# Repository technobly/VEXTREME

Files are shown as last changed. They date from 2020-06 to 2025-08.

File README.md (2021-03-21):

VEXTREME Vectrex Multicart
===

We're carrying on and pushing forward the amazing work of [Sprite_tm](http://spritesmods.com/?art=veccart&page=1) and his Extreme Vectrex Multicart. He posted the code (GPLv3 License) and lots of screens of the PCB/initial schematic, but he never released the PCB. It's a great base for an inexpensive and open vectrex multicart, for developers and players alike!

:warning: Please read this NOTICE of Current Development :warning:
===

**This project is a work in progress, and is not ready for mass production.**  Please observe the currently [posted issues](https://github.com/technobly/vextreme/issues) and there may be more lurking that are not yet identified.  The hardware and software is evolving.  You are free to build any version, contribute and/or follow along.  Please note that support of these pre-releases will be very limited and if you embark on an epic adventure to build one or a few, you should feel comfortable with this type of embedded hardware and software development.  There will be road bumps, but the journey is half the fun of the destination.  When things appear to be stable and we've worked out most of the kinks, we'll change the version to v1.0.  Only then is it advisable to mass produce.

3D Renders
===

v0.2 Render

Video Updates
===

Be sure to subscribe to my Youtube channel for updates!  Here's my [Vectrex playlist](https://www.youtube.com/watch?v=zkJ-z77fJCw&list=PL7MgXfpGKg6CCaIQejZVb5CsTg3-5mHU0&index=1) if you want to stay laser focused on this project.

VEXTREME Discord Server
===
Join the [VEXTREME Discord server](https://discord.gg/VDssGVJ) to chat with us about the development

BOM and Parts ordering
===

All the parts are described in Bill of Materials [vextreme-v0.x.csv](bom/)

Also, you can use this [Digi-Key shared cart](https://www.digikey.com/short/zpdmtp) if you're in a hurry.  It has will have part references right on the packages for you!

Ordering PCB's
===

OSHPark is a good place to order with purple or the new "after dark" theme color scheme.  You can upload the KiCad [vextreme.kicad_pcb](hardware/vextreme.kicad_pcb) there directly.  I would download this entire Github repo ZIP file first though instead of just trying to save the PCB file from your browser.

Another way to order PCB's is by using the included [gerbers-vextreme-v0.x.zip](gerbers) and uploading those with all of the necessary specs to companies like [PCBWay](https://www.pcbway.com) or [JLCPCB](https://jlcpcb.com)

Building and Flashing STM firmware
===

### This assumes you have these prerequisits installed:

- Docker
- dfu-util v0.9
- Make
- Windows will also require these [Zadig instructions](https://github.com/profezzorn/ProffieOS/wiki/zadig)

### Build the stm32-build docker image
```
code/stm32 $ make docker-build
```

### Connect the 2-pin jumper and then connect the cart to USB

### Check if your computer sees the STM32
```
$ dfu-util -l

dfu-util 0.9

Copyright 2005-2009 Weston Schmidt, Harald Welte and OpenMoko Inc.
Copyright 2010-2019 Tormod Volden and Stefan Schmidt
This program is Free Software and has ABSOLUTELY NO WARRANTY
Please report bugs to http://sourceforge.net/p/dfu-util/tickets/

Deducing device DFU version from functional descriptor length
Found DFU: [0483:df11] ver=2200, devnum=22, cfg=1, intf=0, path="20-1.4.3", alt=3, name="@Device Feature/0xFFFF0000/01*004 e", serial="123412341234"
Found DFU: [0483:df11] ver=2200, devnum=22, cfg=1, intf=0, path="20-1.4.3", alt=2, name="@OTP Memory /0x1FFF7800/01*512 e,01*016 e", serial="123412341234"
Found DFU: [0483:df11] ver=2200, devnum=22, cfg=1, intf=0, path="20-1.4.3", alt=1, name="@Option Bytes  /0x1FFFC000/01*016 e", serial="123412341234"
Found DFU: [0483:df11] ver=2200, devnum=22, cfg=1, intf=0, path="20-1.4.3", alt=0, name="@Internal Flash  /0x08000000/04*016Kg,01*064Kg,03*128Kg", serial="123412341234"
```

### Build and flash the STM32 image via dfu-util
```
code/stm32 $ make clean all flash USE_HW=v0.3

// NOTE: Use v0.2 above if you have v0.2 HW, or you may use v0.3 if you make the proper mods to your board.  See "Modifying v0.2 to v0.3"

// You should end up with something like this

Downloading to address = 0x08000000, size = 23536
Download    [=========================] 100%        23536 bytes
Download done.
File downloaded successfully
```

### Remove the cart from USB and remove the jumper (install it on one pin so you don't lose it)

Building and Flashing the multicart's menu
===

### Build the asm6809 docker image
```
code/menu $ make docker-build
```

### Connect the cart to USB with the 2-pin jumper removed

- The first time you do this you will likely have to format the USB drive

  - Name: VEXTREME
  - Format: MS-DOS (FAT)
  - Scheme: Master Boot Record
  - 512 byte page size

- Be patient, it's slow!  Don't worry, copying binaries later will be fast!!

### Build and flash the multicart menu binary
```
// Mac OS
code/menu $ make clean all && cp menu.bin /Volumes/VEXTREME/

// optionally add this to the above command to unmount, after you figure out which drive it is
$ diskutil list
&& diskutil unmountDisk /dev/disk3

// Linux
code/menu $ make copy

// You should end up with something like this, and the binary should have been copied to the root of your multicart drive

asm6809  -B -o menu.bin menu.asm
```

Modifying v0.2 to v0.3
===

v0.3 Mod 1

- To get the new reset feature of v0.3, as of v0.24 software you will need to jumper V-OE pin 12 of the cart fingers (or U3 pin 9) to STM32 pin 29 (PB10).  This may change in the future, don't sell your soldering iron!
- The wire mod above also allows you to play Animaction on VEXTREME!
- More TBD

Adding Vectrex Game ROMs (Binaries)
===

- Create a directory on your multicart called `roms/`

- Add your first binaries there, may I suggest: [Beluga Dreams](https://8-bit-waves.itch.io/beluga-dreams) and [Vec-Man](http://eiti.fh-pforzheim.de/personen/johannsen/projektlabor/vectrex_2019/vectrex_game_vec_man.htm) ?

Docs
===

A nice collection of lessons learned will be [documented here.](docs/)

Hall of Fame
===

If you build one of these, be sure to send me a message with your build pics showing your working VEXTREME multicart!  Or better yet, check out the [hall of fame format here](hall-of-fame/) and submit a PR (please and thank you!)

Credits
===

Everyone who has contributed to this project, with a short summary of their contributions can be found here [CREDITS](CREDITS.md)

LICENSE
===

GPLv3 - essentially you must keep this open, all changes must be disclosed and shared.  Full [LICENSE here](LICENSE) and [TL;DR summary here](https://tldrlegal.com/license/gnu-general-public-license-v3-(gpl-3))

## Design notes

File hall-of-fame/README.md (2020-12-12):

Hall of Fame
===

If you build one of these, be sure to send me a message with your build pics showing your working VEXTREME multicart!  Or better yet, check out the format above and submit a PR (please and thank you!) - limit pic width to 600px please.

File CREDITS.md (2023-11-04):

VEXTREME Vectrex Multicart Credits
===

*If your contribution is not listed below, I appologize!  Please create a PR and add yourself to this list :D*

# v0.0

- [Sprite_tm aka Jeroen Domburg](https://github.com/Spritetm) - [all hardware and software](http://spritesmods.com/?art=veccart&page=1)

# v0.1

- [Bradon Kanyid](https://github.com/rattboi) - all hardware design files and software build
- [Brett Walach](https://github.com/technobly) - minor changes to hardware and software

# v0.2

- [Brett Walach](https://github.com/technobly) - lead VEXTREME developer, hardware & software updates
- [Bradon Kanyid](https://github.com/rattboi) - menu system w/directories, integrating menu.bin into STM binary.
- Tony Lindberg - VEXTREME logo design, machining consulting
- [Malban](https://github.com/malbanGit) - VEXTREME logo optimization, font-5, Vide (used to create and debug VEXTREME), Asteroids emulation
- [Tyler Brymer](https://github.com/TylerBrymer) - High score feature

# v0.3

- [Brett Walach](https://github.com/technobly) - single sided hardware redesign

# v0.4

- [Brett Walach](https://github.com/technobly) - minor hardware updates
- [Vasily Kiniv](https://github.com/v-kiniv) - vector font menu redesign, settings and screensaver features

# DEMOS / GAMES / GCE / LED / MUSIC / TOOLS / XMAS

HUGE THANK YOU TO EVERYONE THAT HAS GIVEN PERMISSION TO INCLUDE GAMES ON VEXTREME!!!

```
- GCE / MB / Jay Smith
- Brett Walach
- Chris BinaryStar
- Chris Parsons
- Clay Cowgill
- Graham Toal
- James Watt
- John Dondzilla
- John Reder
- Malban
- Michael Simmonds
- Nathan Hulett
- Ollie
- Ralf Kornmann
- Rob Mitchell
- Ville Krumlinde

Vectrex Academy
   ├── 2016
   │   ├── Absorbtex by Ana Bressel
   │   ├── Artillery Strike by Jan Langer
   │   ├── Bacteria by Matthias Bach
   │   ├── BaseLoot by Jan Hoffmann
   │   ├── Blox Breaker by Matthias Tiran
   │   ├── Brick Crusher by Tugce Ünsal, Ersin Dogan
   │   ├── Headless Runner by Timo Barth
   │   ├── Hextrex by Michael Tiran
   │   ├── Hungry Python by Maximilian Schiller
   │   ├── Hurdles by Marcel Krause
   │   ├── Laser Wars by Florian Krause
   │   ├── Last Battle by Jonas Krause
   │   ├── Robhop by Miss Lissi
   │   ├── Space Assault by Fabian Pfeifroth
   │   ├── Space Attack by Abdalla Ifen
   │   ├── Spikes by Emanuel Blindow
   │   ├── The Snake by Matthias Schneider
   │   └── Traffic Race by Dominic
   ├── 2017
   │   ├── Block Bomb by Marvin Berstecher
   │   ├── Curling by Manuel Rettig
   │   ├── Doodle Jump by Robin Schelling
   │   ├── Eating Fish by KiriCreamCheese
   │   ├── Hover Race by Simeon Schüller
   │   ├── Kingdom Of Heaven by Jan David Kurfiß
   │   ├── Knight Rider by Blondie
   │   ├── Lost Souls by Gunterson
   │   ├── Pac Men by Manuel Debic
   │   ├── Pipe Race by Ralph Gerath
   │   ├── Shark Attack by by Maximilian Kellner
   │   ├── Space Ball by Tim Stiesch
   │   ├── Space Patrol by Andreas Barth
   │   ├── Spaceship Centauri by Christoph Bechtle
   │   ├── Star Fuel by Andreas Bauer
   │   └── Star War by Marco Schewa
   ├── 2018
   │   ├── Asteroid Cowboy by A.B.
   │   ├── Asteroids by L.D.
   │   ├── Floor is lava by Volcanus
   │   ├── Keyboard Hero by W.L.
   │   ├── Portal Fight by J3W3L5
   │   ├── Pyoro-Chan by Swagger
   │   ├── Split Personality by M.S.
   │   ├── Thirsty Astronaut by Firemedic
   │   ├── Treasure Diver by Falrahch
   │   ├── Yarg! (no Overlay) by Germanke
   │   └── Yarg! by Germanke
   ├── 2019
   │   ├── Blox by Whitehat
   │   ├── Castle Defender by Jumpman
   │   ├── Castle vs Castle by Hydrochous
   │   ├── Daisy Land by Princess Daisy
   │   ├── Dino Runner by Hoid
   │   ├── Donkey Kong by Lionpride
   │   ├── Dont fall by Mr. Chomp
   │   ├── Fencing Simulator by Alberich
   │   ├── Hole-Run Speedy G.
   │   ├── Moon Shot by SchellLabs
   │   ├── Pirates by G. Freeman
   │   ├── Space Defender by KusoTech
   │   ├── Unknown by M4K5
   │   ├── Vec Man by Master Control
   │   └── Vectroid by NATE 66
   └─── 2020
       ├── Climb It by Chris++
       ├── Crash Trexicoot by LiKa
       ├── Maze Of Treasures by Sgt. Pepper
       ├── Number Cruncher by Peer Johannsen Alpha 0.1
       ├── Rotor by Peer Johannsen Beta RC 1.0
       ├── Rotor by Peer Johannsen Beta RC 1.1
       ├── Rush Defense by Compile
       └── Silver Surfer by Hassel
```

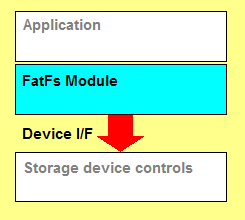
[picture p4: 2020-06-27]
code/stm32/fatfs/doc/img/layers2.png

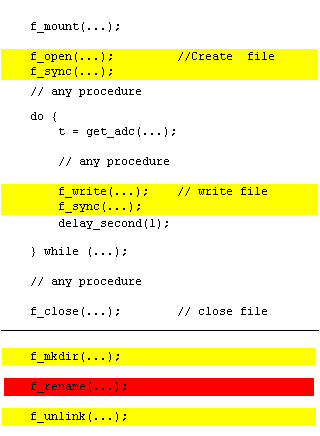
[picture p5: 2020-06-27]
code/stm32/fatfs/doc/img/f5.png

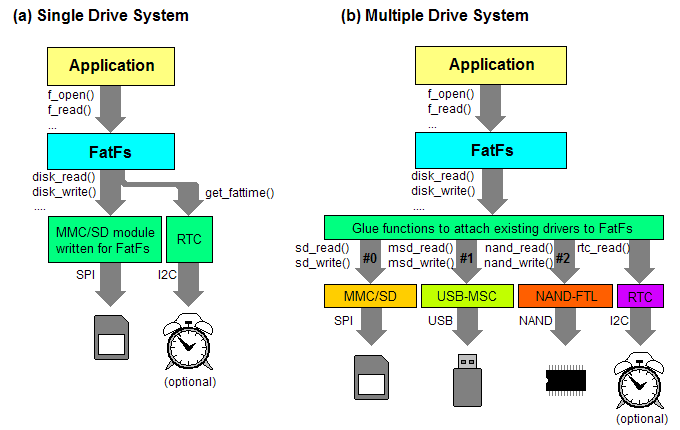
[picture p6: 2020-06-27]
code/stm32/fatfs/doc/img/funcs.png

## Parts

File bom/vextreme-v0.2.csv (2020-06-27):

Ref | Qnty | Value | Cmp name | Footprint | Description | Vendor
C1, C2, C7, C6, | 4 | 2.2u | C | Capacitor_SMD:C_0805_2012Metric_Pad1.15x1.40mm_HandSolder | Unpolarized capacitor
C4, C3, C5, C10, C11, C12, | 6 | 100nF | C | Capacitor_SMD:C_0805_2012Metric_Pad1.15x1.40mm_HandSolder | Unpolarized capacitor
C8, C9, | 2 | 18pF | C | Capacitor_SMD:C_0805_2012Metric_Pad1.15x1.40mm_HandSolder | Unpolarized capacitor
C13, | 1 | 47u | C | Capacitor_SMD:C_0805_2012Metric_Pad1.15x1.40mm_HandSolder | Unpolarized capacitor
CON1, | 1 | vectrex-edge-connector | vectrex-edge-connector | veccart:vectrex-edge-connector-thinner
D1, D2, | 2 | MBR0520 | MBR0520 | Diode_SMD:D_SOD-123 | 20V 0.5A Schottky Power Rectifier Diode, SOD-123
D3, | 1 | LED | LED | LED_SMD:LED_0805_2012Metric_Pad1.15x1.40mm_HandSolder | Light emitting diode
D13, D12, D11, D10, D9, D8, D7, D6, D5, D4, | 10 | APA102-2020 | APA102-2020 | veccart:LED-APA102-2020_6 | RGB LED with integrated controller
J1, | 1 | USB_C_Receptacle_USB2.0 | USB_C_Receptacle_USB2.0 | veccart:USB_C_Receptacle_HRO_TYPE-C-31-M-12 | USB 2.0-only Type-C Receptacle connector
J2, | 1 | Conn_01x06_Male | Conn_01x06_Male | Connector_PinHeader_2.54mm:PinHeader_1x06_P2.54mm_Vertical | Generic connector, single row, 01x06, script generated (kicad-library-utils/schlib/autogen/connector/)
JP1, | 1 | Jumper_NO_Small | Jumper_NO_Small | Connector_PinHeader_2.54mm:PinHeader_1x02_P2.54mm_Vertical | Jumper, normally open, small symbol
R1, R2, | 2 | 22 | R | Resistor_SMD:R_0805_2012Metric_Pad1.15x1.40mm_HandSolder | Resistor
R3, | 1 | 10k | R | Resistor_SMD:R_0805_2012Metric_Pad1.15x1.40mm_HandSolder | Resistor
R4, | 1 | 220 | R | Resistor_SMD:R_0805_2012Metric_Pad1.15x1.40mm_HandSolder | Resistor
R5, R6, | 2 | 5.1k | R | Resistor_SMD:R_0805_2012Metric_Pad1.15x1.40mm_HandSolder | Resistor
U1, | 1 | LM1117-3.3 | LM1117-3.3 | Package_TO_SOT_SMD:SOT-223-3_TabPin2 | 800mA Low-Dropout Linear Regulator, 3.3V fixed output, TO-220/TO-252/TO-263/SOT-223
U2, | 1 | STM32F411RCTx | STM32F411RCTx | Package_QFP:LQFP-64_10x10mm_P0.5mm | ARM Cortex-M4 MCU, 256KB flash, 128KB RAM, 100MHz, 1.7-3.6V, 50 GPIO, LQFP-64
U3, | 1 | 74HC32 | 74LS32 | Package_SO:SOIC-14_3.9x8.7mm_P1.27mm | Quad 2-input OR
U4, | 1 | SN74LVC8T245DB | SN74LVC8T245DB | Package_SO:SSOP-24_5.3x8.2mm_P0.65mm | 8-bit dual supply translating transceiver, 3-state, SSOP-24
U5, | 1 | W25Q128 | W25Q128 | Package_SO:SOIC-8_5.23x5.23mm_P1.27mm | External EEPROM with SPI interface in 8-pin package
Y1, | 1 | 8MHz | Crystal | Crystal:Crystal_SMD_5032-2Pin_5.0x3.2mm_HandSoldering | Two pin crystal

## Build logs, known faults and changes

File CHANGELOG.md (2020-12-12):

# Changelog

## v0.24

Hardware Changes

- rename 'veccart' to 'vextreme' for hardware
- add image for v0.3 wire mod
- Fixes #17, make all pads on addressable LEDS the same size
- Fixes #10 removes soldermask ink around PCB fingers
- Fixes #11 Edge of PCB fingers should be 18.0mm from center of 3.52mm mounting hole and 1.2mm from edge, and slightly enlarged (0.2mm oversized)
- Also aligns holes, fingers and board outline on 0.1mm grid

Software Changes

- Added Turkey Pop.bin to release
- Added HACKS/LEVEL SELECT/Mine Storm 1.bin to release
- Fixed GCE/Mine Storm 1.bin in release
- rename 'veccart' to 'stm32' for firmware, and rename 'multicart' to 'menu'
- Embedded menu binary in STM32 flash image
- Update Dockerfile distro to Arch w/ newer arm-gcc (10.1)
- add .map file to build output
- Dev Mode (cart.bin) and Menu (multicart.bin) should not load a high score
- made high_score_flag readable from parmRam with new RPC ID 16, and speeds memory r/w for highscore
- Implements #55 High Score (by @TylerBrymer PR #56)
- Truncate filenames displayed to 16 characters and fix long filename bug
- Reduced rainbow mode colors so that no-buzz Vectrex owners don't hear any LED modulation
- implemented Animaction support for v0.3 hardware
- made sys_opt.hw_ver usage clearer
- added RAM Write debugging application and new dumpMemory() RPC ID 13
- added a release.sh script
- added standalone Developer Mode app (note: this is for reference only, see readme.md)
- added Develop Mode docs
- added Developer Mode (DM) to Menu.  Press button 2 & 3 at any time to enter DM, or hold them down when starting the Menu.  DM will also automatic re-enter when it's active.  DM is active when a cart.bin is present, and DM can be disabled by removing cart.bin manually, or through the DM menu button 1: Exit.
- add USE_HW compile option, which must now be set.  It will not default to a specific version.  Right now specify it as USE_HW=v0.2 or USE_HW=v0.3 when running 'make clean all flash'.  It can also be exported in your environment if you wish, but don't forget about it if you update your HW ;-)
- removed :leave from DFU commands since after flashing the stm32 binary, we are not really ready to reset and run.  The boot0 jumper must be removed before then.
- minor changes to improve the Makefile for Windows (still WIP)
- changed delay() and millis() to use dwt_read_cycle_counter() instead of the sys_tick_handler() because romemu.S didn't like us randomly leaving to handle interrupts, and we need these functions while we are emulating ROM.  There is a ~35s delay limit because of this.  I added an assert so I don't forget!
- started adding some changes in fatfs to enable writes to flash memory since it was currently read-only, but ended up not needing them.  No worries though, the highscore feature will require these.  These changes thanks to @tbrymer!
- VEXTREME now also prints it's own HW and SW revision in logs at boot time.
- Moved start of rainbow LED code to after we are done with USB activities, so as not to load down the USB port more than necessary.  Hopefully this fixes a reported bug with Windows.
- USB MSC can now be entered while the Vectrex is off, Ejected and left plugged in and the Vectrex can be turned on and boot a cart.bin for Developer Mode, or the VEXTREME menu.
- USB MSC can be started and stopped from the Vectrex now, which is necessary for Developer Mode.
- An improved reset function was added after feedback from users.  Now in v0.3 hardware you will be able to press reset at any time to get back to the Menu.  If you hold reset for ~700ms, it will reset the current running ROM/game.  In the case of booting into Developer Mode (cart.bin already on the drive root), a first reset will not go to the Menu, but rather the cart.bin.. allowing you to skip the cold boot sequence. You may modify v0.2 hardware to act like v0.3 hardware for this feature.  For now that means you will need to jumper V-OE pin 12 of the cart fingers (or U3 pin 9) to STM32 pin 29 (PB10).
- For v0.2 hardware, you can still compile in the old functionality were a short reset would reset the running ROM/game, and if you hold reset for ~700ms you will get the Menu.
- Also added to the reset sequence for both v0.2/v0.3 HW is that the LEDs light up CYAN after the "long" reset delay of 700ms, and stay lit as long as you are holding reset.  When you let go, they return to rainbow.  This helps you gage just how long you need to wait to hold the button for long reset.
- Added "scsi_command: %02X\n" which logs USB MSC commands to log output, this might seem chatty, but for now let's see what we see ;-)
- Set USB power to 500mA (was set to 100mA)

## v0.23

- Fixes issue where VEXTREME takes several minutes to mount as USB drive on Windows #53

## v0.22

- ignore all file extensions that are not .bin or .vec (case insensitive) #49
- increased quick reset delay to 700ms #45 
- adds HW/SW version to VEXTREME menu and games #48 
  - see example in LED Test v1.1.bin

## v0.21

- :warning: Added NOTICE of Current Development
- Fixes Polar Rescue and implements a new Reset Heurisic #37
- Adds addressable LED control and demo #41
    - added 3 functions to control the LEDs from a Vectrex program
        - updateOne() - RPC 6
        - updateAll() - RPC 4
        - updateMulti() - RPC 7
    - added RPC function 5 to step through rainbow control of LEDs in menu
    - added "LED TEST" which uses updateMulti to show how to finely control
    all of the LEDs with a test program.  Press UP on the joystick, try it slowly as well :D
    - added addressable LED control to Veccy Bird v1.5

## v0.2

- Replaced USB-B-mini with USB-C and centered USB on cart
- Extended the PCB by 1.7 mm to get the USB-C connector as close to the case exterior as possible.
- Widened the PCB to 48.0 mm so that there’s less side to side play in the cartridge slot.
- Moved outer mounting holes into the proper locations
- Reversed D3 and R4 order to get D3 closer to edge of the PCB, but it turned out we added something else there!
- Added 10 APA102-2020 addressable RGB LED lights (max. draw 245mA) … qualify with USB-IN (PA9) for 100% brightness, else 50%
- Added 47uF cap for peak currents required for RGB LEDs.
- Added V-IRQ connection to PB9 for 128KB bank-switching
- Grounded unused floating inputs on U3 to reduce current consumption
- Adjusted Y1 to use 12pF load crystal resonator with 18pF load caps (see equation)
- Lots of clean up and tweaking all over PCB
- Added revision to PCB
- Added “VEXTREME” to PCB
- Added a ground pour under the STM32
- Made the contacts on the edge connector thinner (1.52mm) and made sure they were spaced properly (2.54mm).
- Started moving footprints to the libs/veccart.pretty library so you know where they will be!
- Add basic folder support #1
- Ignore dotfiles generated by MacOS
- Add software driven addressible LED support
- improve USB write time for a single game by 3x (32KB in 1 second)
- adds 'clean' and 'all' rules for multicart build
- create 4KB of space for menu (currently about 2KB), and reserve 60KB for menu data.
- Added a mostly optimized 100 vector logo for VEXTREME
- Added a much improved version of Malban's 5 line font (everything except lowercase, don't use lower)
- Reduced menu to 4 items at a time
- Added a special intro jingle that's been stuck in my head (enjoy!)
- temp increase time to reset to allow Fortress of Narzod to play
- Extract menu code from main code and optimize menu code
- Add basic menu labels/function-per-button support #4
    - At the bottom of the menu 1 = (BACK), 2 = PAGE LEFT, 3 = PAGE RIGHT, 4 = SELECT
- Ignore lst files #5
- adds ISSUE_TEMPLATE.md and PULL_REQUEST_TEMPLATE.md for contributions from the community
- Update to latest (pinned) libopencm3 #6
- Fixed lastselectcart on wrong game after reset
- Fixed do not inc page if next one will be blank issue
- Converts logo from sync to smart list, thanks Malban!
    - Note: Had to replace NOP MACROs with JSR of approx equivalent value
    - Converted fcb hi(label),lo(label) into fdb label
    - Reduces cycle count by 8 - 10k!

## v0.1

- Mostly unchanged from Sprite_tm's original HW/SW design
- Mostly unchanged from Rattboi's original PCB design
- fixes error opening PCB with latest KiCaD
- add gerbers for easy PCB ordering at many places
- update README.md and add LICENSE
- fixes premature automatic reset delay on GCE Vectrex
- fixes menu builder missing filename in path
- pretty up the menu by removing the .BIN file extension, and other cleanup
- let's call it the VEXTREME cart, for now. (original name was EXTREME)

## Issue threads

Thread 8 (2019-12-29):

DS243x support for High Score/etc save

gauze, 2019-12-29:
## Feature/Enhancement Request

one thing I'd be interested in seeing is emulation of the Maxim DS243x
1-wire eeprom used on various games to store high scores and
settings/options. The device is controlled through cart pin 35 (port B
bit 6 from PIA) code examples from Alex Herbert/Malban can be found in
the "include" file ds2431LowLevel.i that is in VIDE and other stuff.
The datasheet for the device describes way more functionality than
you'd need to implement the simple read/write that Vec games use.

https://datasheets.maximintegrated.com/en/ds/DS2431.pdf

thanks

technobly, 2019-12-31:
Thanks @gauze for the feature request!

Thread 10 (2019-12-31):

[PCB,v0.2] soldermask around PCB fingers

technobly, 2019-12-31:
## Bug Report

### Expected Behavior

There should be no soldermask ink/LPI surrounding the PCB fingers

### Observed Behavior

There is soldermask around the fingers, and when it's really thick it causes the contacts in the Vectrex connector to float above the PCB finger ever so slightly.  Games glitch out at different times due to addressing issues or bad data.

### References

Here's a great list of Vectrex carts that also have this issue (notice the original GCE carts pictured here DON'T have this issue but do have hard gold fingers as well...): http://vide.malban.de/collection-2/the-beauty-in-pcbs

See the issue and resolution here for v0.2: https://www.youtube.com/watch?v=sS-BKoMr4OM
The tool used in the video above is an exacto knife with the tip broken off on purpose :D

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

### If you bought a VEXTREME from Game-Tech.us, it is a v0.2 with the soldermask problem (PLEASE READ)
Is your game glitching out at random times, or only Mine Storm showing up? Your problem is almost 100% because of the soldermask that surrounds the fingers on the cart. This is why I painstakingly removed it from all v0.2 VEXTREME's that I sold for $40 USD. Jason GameTechUS knows this is a problem and sold them to you without removing the soldermask, because they might have worked in his Vectrex... I don't know his testing process... but YMMV with different connectors and varying degrees of soldermask thickness. Not trying to throw anybody under a bus here... just real talk. I don't want VEXTREME (all caps btw) to get a bad name because a pre-production version not ready for the masses was sold in high numbers. Good luck all you new owners of open source hardware, I do hope you get to enjoy VEXTREME as I intended in creating this project. I hope Jason GameTechUS stands by his sale and helps you find a solution here.

Here's a way to test if it's the fingers causing an issue: take the cart out of the shell... plug it in, play a game, and gently and slowly wiggle the cart up and down and maybe even pull it 0.5 mm in and out of the cart slot. If the game glitches out on you... soldermask is likely the issue. Try this same procedure with any production Vectrex game, and you'll see it won't glitch out... and you can also see what the limits of pulling it in and out are.

You can also try that same procedure with the game in the shell, but it won't go up and down as easily. More so in and out, and it will be worse in the case because the case holds the PCB perpendicular to the cart edge connector, so all of the fingers of the Vectrex's connector tend to float on top of the soldermask at the leading edge of the PCB.

Closed 2020-06-11.

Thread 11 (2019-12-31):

[PCB] Edge of PCB fingers should be 18.0mm from center of 3.52mm mounting hole and 1.2mm from edge, and slightly enlarged

technobly, 2019-12-31:
## Enhancement

For proper mating of the PCB to Vectrex when PCB is installed in a reproduction Vectrex cartridge enclosure, the PCB fingers should be 18.0mm from the center of the 3.52mm mounting hole and 1.2mm from the PCB edge.

This 1.2mm distance just also happens to be a requirement for hard gold PCB finger 45° edge beveling: https://jlcpcb.com/quote/pcbOrderFaq/Gold%20Fingers

See Berzerk cart measurements:
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

---

Mounting holes should also all be 0.2mm larger than the posts (currently they are 0.1mm larger and it's perfect... but too perfect of a fit)

POST - HOLE
--------------
5.0    ->    5.2
4.0    ->    4.2
3.5    ->   3.7

Closed 2020-06-11.

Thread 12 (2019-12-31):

[PCB] Remove D8 - D13 and just have addressable LEDs on the edge of the board, spacing the 4 LEDs evenly

technobly, 2019-12-31:
## Enhancement

Not much more to say other than `7mm spacing` between all 7 LEDs is some kind of jackpot I think! 🎉 💰

----

UPDATE: After more testing, 4 LEDs can but turned up to full brightness instead of using 7 LEDs.  Less cost, and same amount of light.  Yeah we have less resolution for cool light shows, but... from what I can tell everyone want to cover up the LEDs with a cart of some sort anyway.

Closed 2020-06-12.

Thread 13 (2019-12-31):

[PCB] Move the debugging/serial port connector so it does not interfere with enclosure bosses.

technobly, 2019-12-31:
## Bug Report

### Expected Behavior

Components should not be in the way of the enclosure bosses

### Observed Behavior

- 5 pin debugging header pins are in the way (you can flush cut these pins as a workaround)
- D4 LED is in the way, but really it's so thin it doesn't matter much.

### References

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

Closed 2020-06-13.

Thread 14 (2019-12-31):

Hardware STM32 SPI2 support for addressable LEDs

technobly, 2019-12-31:
## Feature

Currently the addressable LEDs are bit-banged with software SPI.  Ideally we'd like to support HW SPI2 so that we can do fancy things like DMA control of the LEDs.  To enable that, we'll likely have to shuffle some pins around.

Notes:
- Move V-HALT and V-CE to different pins and fix SDAT and SCLK so they are on SPI2 for hardware control.
- V-CE might be optimized for MSB (seems like it is in romemu.S), so move to PA15 which bumps CSn to some other pin?
- CSn should likely be on SPI1_SS, but it might not matter (check). PB01 is used in an optimized way as well though.

Alterac, 2020-03-03:
What about changing the part your using for RGB Leds to something simpler (and easy to source from lcsc) like the WS2813B and then you can use only 1 Pin, say PB8 - SPI5_MOSI to control them?

technobly, 2020-03-03:
Thanks for the idea @Alterac! WS2812B/13's are very timing dependent... so these would not be as flexible and resilient as Clock&Data IMO, which can be done very slowly if necessary.  We have tons of pins available... so it's just an exercise of juggling resources at this point.  WS2812B/13's are quite large as well.  I do agree on the sourcing issue though... there must be an easier/cheaper place to get these LEDs from than Digi-Key.

Alterac, 2020-03-03:
The PCB has lots of room, so i wouldnt be too worried about that, but 10 RGB leds is still quite extravigant imho, I think 4 would be more than enough (but whatever, i can just not solder on the rest, hah). But the point about clocking them is much easyier since you dont need to babysit the timing code.

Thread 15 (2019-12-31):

[PCB] Replace U3 with a single OR gate

technobly, 2019-12-31:
## Enhancement

Currently U3 is a quad 74HC32 with only one gate being used.  This was chosen originally to keep the design choices Sprite_tm made for v0.1.  It's a bit cheaper and requires less space to add a single gate version of this.  Keep the package a reasonable size for hand assembly.

https://lcsc.com/product-detail/Gates-and-Inverters_Texas-Instruments_SN74LVC1G32DBVR_Texas-Instruments-Texas-Instruments-SN74LVC1G32DBVR_C10096.html

rattboi, 2020-01-03:
perhaps we could move the OR logic into the romemu itself? Would require another GPIO though.

technobly, 2020-06-14:
I ended up adding both options :D

Closed 2020-06-14.

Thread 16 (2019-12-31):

[PCB] Replacement for U4 (SN74LVC8T245DB) which is more generally available (at LCSC)

technobly, 2019-12-31:
## Enhancement/Bug

- Replacement for U4 (SN74LVC8T245DB) which is more generally available (at LCSC)
- I had tried [this part SN74LVC4245A](https://lcsc.com/product-detail/74-Series_Texas-Instruments-SN74LVC4245APWR_C7859.html) but despite it having the same pinout it doesn't work, the Vectrex ends up not being able to read anything.

Alterac, 2020-03-03:
Part is already stocking at LCSC, could probably close this
https://lcsc.com/products/74-Series_488.html?q=SN74LVC8T245DB

technobly, 2020-05-31:
Thanks @Alterac

Closed 2020-05-31.

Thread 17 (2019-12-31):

[PCB] Make all pads on addressable LEDs the same size

technobly, 2019-12-31:
## Bug Report

The addressable LEDs don't like to sit flat when reflowing because the pads in the 4 corners are larger than the center pads.  Make all of the pads the same size, so the part snaps into place and doesn't require any touch up work or extra fiddling.

Closed 2020-06-12.

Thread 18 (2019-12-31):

[PCB] Add ESD protection to external connections (mainly USB)

technobly, 2019-12-31:
## Enhancement

USB-C D+/D-/CC1/CC2 connections need an ESD protection device added.

Tiny, but has 4 devices in one package
https://lcsc.com/product-detail/Diodes-ESD_Texas-Instruments_TPD4E05U06DQAR_Texas-Instruments-Texas-Instruments-TPD4E05U06DQAR_C138714.html

Dual device
https://www.ti.com/product/ESD122

Dual device, larger easily hand solderable (SOT-23-5)
https://lcsc.com/product-detail/Diodes-ESD_NXP_PESD3V3S2UT-215_PESD3V3S2UT-215_C84276.html

Closed 2020-06-14.

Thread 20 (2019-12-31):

[PCB] Move debugging / programming headers to USB-C edge of board

technobly, 2019-12-31:
## Enhancement

- Debugging header: Reduce 5 pin header to 3 pin header to reduce size?
- Debugging header: make it right-angle SMT?
- Programming header: Make 2-pin jumper a right angle switch instead of a jumper?

Closed 2020-06-14.

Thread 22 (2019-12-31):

[v0.2] Polar Rescue crashes when the sub launches

technobly, 2019-12-31:
## Bug Report

### Expected Behavior

It should just play normally

### Observed Behavior

Polar Rescue crashes when the sub launches

### Steps to Reproduce

Load up Polar Rescue with v0.2 and launch your sub... black screen.

technobly, 2020-01-01:
From Malban:

If I remember right this is the same sort software "problem" as with minestorm.
See: http://vectrex-emu.blogspot.com/2006/07/talking-about-history.html
- > 07/07/2006

If you fill the "rom" space with e.g. "1" than it should work. (Maybe on proboard there is somewhere an attachment)

Copied here for preservation:
```
Finally located the bug in MineStorm that drew garbage vectors for a few seconds when a fireball mine was shot before it became active.

It was in fact an error in the original code of minestorm, not in the emulator : In the mines rendering code, drawing an inactive fireball mine that was destroyed ended up in rendering a list that was located in the cartridge rom space (which is empty, since Minestorm is running)!

Once the bug was identified, the cure was extremely easy : initialising the cartridge rom space with $01, so that every location in this space is an empty Vector List.

Here is the comment added to the removeCartridge() method in VectrexMemory.java:
/**
* We fill with $01 to bypass a bug in MineStorm (invalid
* reference to the ROM area, when a fireball mine is hit by
* a bullet while it is not yet moving). This could be fixed
* around here in the ROM :
*
* launch_fireball:
* EC17 [86.04.........] LDA #4
* EC19 [A7.41.........] STA 1,U
* EC1B [0A.EA.........] DEC <$EA ; $C8EA
* EC1D [7E.EB.53......] JMP check_next_bullet ; $EB53
*
* Somewhere in this routine there should have been :
* LDA #8 ; mark fireball as active
* STA ,U ; store mine state (if it wasn't moving, state was $10)
*
* Actually, when a stationnary fire mine is hit, the program ends
* up drawing a VL located at $3408 (because it assumes that an
* object that's not moving is either a dumb / fire / magnet /
* magnet+fire mine, whereas here it's a fireball!
*
* So to fix this we just fill the ROM with ones so that it
* becomes a big empty vector list.
*
*/
```

technobly, 2020-01-01:
Found the link to ProBoards here: http://vectorgaming.proboards.com/thread/1778/polar-rescue-on-vecmulti

It's claimed that just appending 24Ki of 0x01 to the 8Ki of Polar Rescue fixes it on VecMulti, but I tried that with this file [Polar Rescue (24K x01).bin](https://www.dropbox.com/s/2cxh0noaiafsav4/polar%20rescue%20%2824k%20x01%29.bin?dl=1) and it still crashes.  The other file from proboards doesn't exist anymore, but it was done the same way.

Closed 2020-01-13.

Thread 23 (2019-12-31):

Developer mode, allow the cart to stay plugged into a computer and appear as a RAMDISK

technobly, 2019-12-31:
## Feature

Developer mode, allow the cart to stay plugged into a computer and appear as a RAMDISK

Here's an idea of how this might work:
1) Vectrex -> press 2 + 3 at any time
2) Vectrex -> call new rpc command to tell stm32 it's in dev mode
3) STM32 -> enter ramdisk mode (which could just be the same as usual, it's fast enough.. or later maybe use RAM for insta speeds)
4) STM32 -> write to SETTINGS struct indicating USB DEV WAIT mode is active (maybe SETTINGS will be saved in NVM at some point, but not necessary right now since USB will have power plugged in)
5) STM32 -> watch for new file w/ special name
6) STM32 -> figure out "done" (writes start and complete for filename called cart.bin)
7) STM32 -> write to SETTINGS struct indicating USB DEV RUN mode is active
8a) STM32 -> reenter romemu booting up multicart.bin
8b) Vectrex -> running multicart.bin read SETTINGS struct to know if we are in mode USB DEV: WAIT, RUN or DISABLED.  If WAIT, jump to 2.  If RUN, proceed to 9. If DISABLED jump to 11.
9) Vectrex -> read buttons first to know if we should exit USB DEV mode.  If we see 2 + 3 held, set USB DEV DISABLED in SETTINGS, bail out and busy wait for them to be released so we don't re-enter USB DEV mode immediately.
10) Vectrex -> if no buttons held and USB DEV == RUN, set USB DEV == WAIT and call rpc command to load cart.bin
11) Vectrex -> otherwise if disabled just run the menu as usual.
12) STM32 -> if reset, jump back to 8 as usual and it should see USB DEV == WAIT getting us back to USB DEV mode.

[EDIT: ... it's way more complicated than this... and I dread updating this flowchart!]
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

Other considerations:
1) Messages on screen should not reach full brightness, and should move around in a screensaver like fashion to wear the screen evenly
2)

Closed 2020-05-24.

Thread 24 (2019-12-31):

Add cartridge RAM support

technobly, 2019-12-31:
## Feature

Add cartridge RAM support (specifically for Animaction $2000-$27FF, but possibly for others as well).

Any downside to letting the entire 32K/64KB of emulated ROM to be considered as RAM and writable?

phillipeaton, 2019-12-31:
I'd like the ability to have more RAM, 1kb is a bit small for Forth
development.

Cheers,
Phil

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

technobly, 2019-12-31:
@phillipeaton Animaction is 2Ki, but the desire would be to just enable the whole thing to be writable.  Do you see any downside to that?  How much RAM does Fourth require, and what memory address range do you currently use?  Do you have to do anything special in your program to enable it on VecFever?

phillipeaton, 2020-01-01:
The downside of it all being RAM is that some bad code might try and write
to the ROM address space, if it's ROM, it's a harmless write, if not...

Do any programs do that? Probably not, but who knows? I guess it would be
OK to make all the non-ROM address space work as RAM up to the 48k limit.

Forth (not Fourth) in the early days was bootstrapped from disc into RAM,
there was no ROM. Nowadays, RAM and ROM is plentiful and cross compilers
exist, so you can get by with less. Currently I'm using whatever is left in
the Vectrex 1k that isn't BIOS reserved, probably about 750 bytes, which is
good enough for some buffers, stacks, user variables and quite a few test
words, but you couldn't dump a whole program onto the Vectrex and let it
compile it into RAM. Running a Forth multi-tasker in 750 bytes is also
probably a non-starter, though not sure what the performance hit would be
anyway.

Thomas told me that extra RAM could be configured in the VecFever, but we
never got round to setting it up, so all I'm using that is special in the
VecFever is an extra serial port. Originally he supplied a Prolifics PL2303
device, but that has dodgy drivers on Windows, so he gave me an FT232
device that works much better. The serial port is enabled using some bytes
in the cart header block, the baud rate is setup in the VecFever menus. It
also provides 256 byte buffers, probably for send and receive.

I can send you the cart header block of you're interested.

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

technobly, 2020-01-01:
From Malban:
>About the RAM: I can tell how the VecFever does it :-). Per default the complete "ROM" area is writeable (AKA RAM). But there are some games that actually (bugy!) write to ROM and destroy the running game (some of pcJohn's games) - so that not always is a good option. So the VecFever allows to switch on a ROM mode, where the ROM area is not writeable! Binaries for the VecFever are saved in "V4E" format... that format includes a header for various options... (like size, bankswitch scheme, RAM/ROM needs cartridge options etc).

If the V4E header schema is open and sharable, please do share it.  I don't know why it wouldn't be open since it's for creators of games for VecFever, but I can't say that I've run across it anywhere :)  I don't want to copy it, but there could be value in parsing it so you wouldn't have to create separate ROMs for VecFever and VEXTREME.

I believe Malban uses the extra RAM in VecFever for Vectorblade.  48Ki of RAM.

gtoal, 2020-04-17:
A bit mask on the vextreme side could be used to mark RAM areas as writable or read-only.  Depending on the memory available in the vextreme to store this bitmask, a bit could modify read/write behaviour for anything between 4K blocks all the way down to single bytes.  Also if more than one bit is used, it could represent more than just a read/write flag - it could be used to trigger an NMI interrupt to be serviced by the 6809 which would allow the 6809 to implement virtual peripherals rather than requiring the virtual peripheral support to be baked in to the ARM side (eg as per Philip Eaton's request for an addressible serial port - with this a read could be trapped and the NMI code could call the vextreme via RPC before placing the fetched value in a register or at a fixed addess in 6809 memory like a DMA transfer)  This mechanism could also be used for placing breakpoints in the rom for debugging 6809 execution.

technobly, 2020-04-18:
Since VEXTREME now ignores all files besides .vec/.bin case insensitive, I was thinking we could just put a .txt file with the same name as the game that is loaded, where special settings could be enabled just for that game.  Most games would just use the default settings and not require this file.  We could make a special file type and/or extension, but I feel like that's just going to confuse people.  Everyone can edit a text file, right?  If it gets saved without the .txt extension it would still work.

E.g.
Animaction.bin
Animaction.txt
```
# VEXTREME_ROM_OPTIONS_FILE
#
# RAM_RW - RAM Read/Write
# <R/W OPTION>,<START>,<END>
# READ_ONLY,0,7FFF (default),
# READ_WRITE,<START>,<END>
RAM_RW=READ_WRITE,2000,27FF
```

technobly, 2021-05-11:
FYI: I ran into these things recently!

@phillipeaton
> "The downside of it all being RAM is that some bad code might try and write
to the ROM address space, if it's ROM, it's a harmless write, if not...
Do any programs do that? Probably not, but who knows? I guess it would be
OK to make all the non-ROM address space work as RAM up to the 48k limit."

@malbanGit
> "But there are some games that actually (bugy!) write to ROM and destroy the running game (some of pcJohn's games)"

---

So I implemented the RAM cart specific options tonight :D

- I first modified the romemu.S to allow for variables to be used for RAM enable, start, and end address
- Created a Cart Options structure
- Created a Cart Options check/load/get/close function
- For every file loaded, it also checks if there is a matching *.ini file... if so it attempts to load it.  The options get parsed and the game is executed with RAM supported at the desired location, or not.  It works great!

Now RAM will be disabled unless we request it by adding a matching game.ini file.  The ini file is binary data, but super simple to create by hand, and rarely used.

```
40 00 01 00 01 20 7F 00 00 00 00 00 00 00 00 00 00 00 00 00 00 00 00 00 00 00 00 00 00 00 00 00 00 00 00 00 00 00 00 00 00 00 00 00 00 00 00 00 00 00 00 00 00 00 00 00 00 00 00 00 00 00 00 00
```

data is encoded in little endian format

0x0040 = 64 bytes for size
0x0001 = Version 1 Cart Options format
0x01 = bit 1 set, RAM enabled (other bits not used currently)
0x20 - high byte of start address (aka 0x2000)
0x27 - high byte of end address (aka 0x27FF)
This is for Animation of course

If you wanted to only allow 0x2000 to 0x20FF, you would specify it like this
0x20 - high byte of start address (aka 0x2000)
0x20 - high byte of end address (aka 0x20FF)

Logo Lite would be
0x60 - high byte of start address (aka 0x6000)
0x7F - high byte of end address (aka 0x7Fxx)

Technically Logo needs RAM all of the way to 7FFF, but we will run into a problem with that if it ever reaches the top, because that's how we call our RPC functions.  So, we'll need to move those to >=0x8000 ;-) But for now you'll be hard pressed to reach 0x7FFF with Logo Lite.

Closed 2020-05-26.

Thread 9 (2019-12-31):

[PCB,v0.2] R4 & D3 reference designators are swapped

technobly, 2019-12-31:
## Bug Report

The components are in the correct place here:
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

Just the R4 and D3 reference designators need to be swapped.

So if you build v0.2 unmodified, make sure your components look like the picture.

Closed 2020-06-12.

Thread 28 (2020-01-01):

Add support for Voom! (Doom on Vectrex)

technobly, 2020-01-01:
## Feature/Bug Fix

This is pretty straight forward and already has been compiled by @technobly and @rattboi, but there is an issue where the frame rate is slow and not consistent either.  Also some lines appear to be out of place where they should be.

Should be smooth like this: https://www.youtube.com/watch?v=VuVnoqFF3II

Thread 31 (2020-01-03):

Better Reset Heuristic

technobly, 2020-01-03:
## Enhancement

### Currently the reset mechanism works like this:
- reset a counter when ROM emulation starts (menu is loaded of a game is requested to be loaded)
- increment a counter every time the cartridge is read from
- when you see the copyright symbol address 0x0004 being read, check if that counter is above a certain value
- if so, assume the game has been reset and the cart header is being read again and take action to bring the menu back up
- if not, just keep on reading and incrementing the counter

### New Reset Heuristic

- We need a better heuristic for determining when the Vectrex has been reset.
- Games like Polar Rescue have bugs that end up causing the copyright header addresses to be read during the game causing false tripping
- Also this current time based + address detection heuristic is not that reliable... for example if a game had a really long intro music tune it would cause false tripping (I don't actually understand why long intro music causes the reset timer to show as expired, because the header is read before the music starts playing, but that is the observed result)

### References

- #22
- Use open source tools to help figure this out.  Two of these 16 channel logic analyzers: https://sigrok.org/wiki/Lcsoft_Mini_Board
- Can be read from at the same time and potentially have their captures stitched together to form a 32ch analyzer: https://sigrok.org/bugzilla/show_bug.cgi?id=1249

gtoal, 2020-01-09:
Doesn't a press of the reset button always cause a fetch of the 6809 reset vector?  Would that be sufficient to detect it?

technobly, 2020-01-09:
Yes that’s something I’m currently exploring. Thanks @gtoal !

technobly, 2020-01-13:
Closed by #37

Closed 2020-01-13.

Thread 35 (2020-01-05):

Takes several minutes to mount as USB drive on Windows

technobly, 2020-01-05:
## Bug Report

### Expected Behavior

When attaching the USB to Windows 10, the VEXTREME MSC(Mass Storage Controller) should mount a couple seconds and show up in Explorer.

### Observed Behavior

When attaching the USB to Windows 10, the VEXTREME MSC(Mass Storage Controller) does not mount for several minutes.

The USB MSC driver does load in a few seconds, but then nothing happens on the device for several more minutes.

### Steps to Reproduce

- Remove the 2 pin jumper
- Make sure it's not powered already by the Vectrex
- Plug it into the USB port of a Windows 10 computer

### Failed attempts to resolve the issue

- I tried reformatting as FAT and recopying the games from Windows, and that took the expected time.  Copying and deleting single files is blazing fast for a cheap 16MB SPI flash chip.
- Uninstalling various drivers like USB MSC, Host Controller, etc.. and restarting the computer
- Running DriveCleanup 1.6.0 with VEXTREME removed, restart, etc..
- Disabling AutoPlay (physically turning it off completely in settings)

### References

- As a point to note, it seems [tons of people have this issue on Windows](https://www.google.com/search?q=USB+drive+takes+several+minutes+to+mount+windows+10)

Closed 2020-04-21.

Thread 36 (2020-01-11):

[PCB] Add test points for power rails

technobly, 2020-01-11:
### Enhancement

Add some nicely labeled test points for power rails:
+5V
+3.3V
Vectrex VCC
USB VUSB
GND

Closed 2020-06-14.

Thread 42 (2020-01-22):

[feature] Screen saver / mini game

gtoal, 2020-01-22:
After leaving my vectrex powered up all day it occurred to me that the bright "VEXTREME" at the top of the screen might lead to burn in, in the long term.  Perhaps after a period of inactivity, the default screen could fade out everything except the word VEXTREME, and have it bounce across the screen in a path that eventually covers all positions.  Original screen to be restored on any joystick/button activity.

technobly, 2020-04-21:
That's a good idea @gtoal !  How about after a timeout, the menu turns into a mini game? It would just be in demo mode until you grabbed the controls, and then, you'd be in!  Button 1 would exit.

technobly, 2020-05-04:
BTW, I have built Developer Mode #23 from the ground up with screen wear in mind ;-)

Closed 2021-03-20.

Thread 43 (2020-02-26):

C13 value query

smartyuk, 2020-02-26:
The BOM (veccart.csv) lists C13 as 47uF but the Digikey shared cart has C13 listed as a 0.047uF. Can you please confirm which is correct?

*UPDATE*, I can see the schematics say 47uF.

technobly, 2020-04-18:
Thanks @smartyuk :D Fixed, and added all parts to the shared cart.

Closed 2020-04-18.

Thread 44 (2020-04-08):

v0.21 quick reset pulse too short for no-buzz Vectrex

technobly, 2020-04-08:
## Bug Report

### Expected Behavior

A quick tap of reset will reset the current game.
A longer press of reset will reset to the VEXTREME menu.

### Observed Behavior

The no-buzz Vectrex (UK models 31xxxxx and higher) seem to have a minimum 300ms reset pulse.  The reset timer in v0.21 was approx 300ms, and it's not possible to reset the current game with a no-buzz Vectrex.

### Steps to Reproduce

See above

### References

See this FB thread: https://www.facebook.com/groups/vectrex/permalink/1262033124007062/?comment_id=1264366317107076

Closed 2020-04-09.

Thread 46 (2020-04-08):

RGB LEDs causing faint buzzing bees noise due to power supply modulation

technobly, 2020-04-08:
## Bug Report

### Expected Behavior

For the most part, but totally silent.

### Observed Behavior

The LEDs on VEXTREME v0.2 tend to oscillate/modulate at [evil frequencies 666hz](https://www.szynalski.com/tone-generator/?#666,saw,v0.16) when the brightness is limited based on the color value 0x0 ~ 0xFF for each R,G,B.  When it's not 0xFF, you'll hear this extra buzz.

If you have a no-buzz Vectrex, it will be more obvious.  You can't have all 10 LEDs on at full brightness.  It's too much current for the Vectrex.

Hardware filtering seems like an obvious solution, but it turns out that software is a better one.

### Steps to Reproduce

Use a v0.2 VEXTREME to run the Test Cart rev.4 and set it to Deflection test.  When the vectors turn off, you'll notice that there is this evil buzzing of bees.

Closed 2020-04-10.

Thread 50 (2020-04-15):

Create a serial port in the Vectrex address space

phillipeaton, 2020-04-15:
A serial port connected to a terminal emulator on a PC is handy for debugging and allows interactive environments like Forth or BASIC to run.

I'd like a serial port to run something similar to my serial port handler that works on a VecFever (code below is in Forth):

HEX

\ VecFever UART serial port interface. VecFever provides buffering (256 bytes each way?)
7FFB EQU v4eTxStatReg \ Read, negative if transmit buffer is in use, positive otherwise
7FFB EQU v4eTxByteReg \ Write
7FFC EQU v4eRxStatReg \ Read, zero if no data received, otherwise != 0
7FFD EQU v4eRxByteReg \ Read, upon reading, 7FFC is automatically cleared
7FFE EQU v4eLEDReg    \ LED Register, probably read/write?

CODE KEY?   \ -- f    return true if char waiting
  6 # ( D) PSHS,   CLRA,   v4eRxStatReg LDB,
  NE IF,   -1 # LDB,   THEN,   NEXT ;C

CODE KEY    \ -- c    get char from serial port
   6 # ( D) PSHS,   BEGIN,   v4eRxStatReg LDB,   NE UNTIL,
   v4eRxByteReg  LDB,   CLRA,   NEXT ;C

CODE EMIT   \ c --    output character to serial port
   BEGIN,   v4eTxStatReg  LDA,  MI UNTIL,
   v4eTxByteReg STB,   6 # ( D) PULS,   NEXT ;C

**Describe alternatives you've considered**
Other alternatives are available, but a VEXTREME is cheaper than the other alternatives and/or potentially provides a lot more functionally.

gtoal, 2020-04-17:
This - and any other virtual devices added by the vextreme - might be placed in the C000-C7FF space so as not to interfere with the rom space (0000-BFFF).  Although I'm not sure why a virtual device interface is better than the existing RPC mechanism for calls to the Vextreme?

phillipeaton, 2020-04-17:
All I know about RPC is that it can mean Remote Procedure Call. How would I
use that in place of a serial terminal? Can you point me to the code?

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

gtoal, 2020-04-17:
> All I know about RPC is that it can mean Remote Procedure Call. How would I use that in place of a serial terminal? Can you point me to the code?
> […](#)
> On Fri, 17 Apr 2020, 18:17 Graham Toal, ***@***.***> wrote: This - and any other virtual devices added by the vextreme - might be placed in the C000-C7FF space so as not to interfere with the rom space (0000-BFFF). Although I'm not sure why a virtual device interface is better than the existing RPC mechanism for calls to the Vextreme? — You are receiving this because you authored the thread. Reply to this email directly, view it on GitHub <[#50 (comment)](https://github.com/technobly/vextreme/issues/50#issuecomment-615336366)>, or unsubscribe <https://github.com/notifications/unsubscribe-auth/AKRZ2LT7VX54I2TR2KDN5LLRNB6KHANCNFSM4MIXR4MA> .

here's the led test which sends commands to the vextreme arm by rpc - look for rpcfn near the end of the file:
https://github.com/technobly/vextreme/blob/master/code/led/led-test1/led-test1.asm

I don't know for sure that serial I/O is available via this mechanism but if it isn't, it should be!

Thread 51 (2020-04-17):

Data logger feature?

gtoal, 2020-04-17:
This is a suggestion to enhance the Vextreme for use as a program development/debugging aid.

The Vextreme could be used as a substitute for an expensive logic analyzer/data logger, by recording the program execution path and accesses to rom data, by having the Vextreme keep a cyclic buffer of the addresses that were fetched from, during program execution.

I'm assuming the hardware is not fast enough to log directly to flash on the fly, which is why I suggest the use of a cyclic buffer.  If it were, that would be a preferable option as the size of the log could be much greater.  Saving a rom access record using a cyclic buffer would look something like:  Buff[Ptr] = fetch_addr; ptr = (ptr + 1) & buffsizemask; which should be low enough overhead that it can be done on every fetch.

Depending on RAM available it would also be useful to store an accurate timestamp by using the ARM internal cycle counter.  If using a timestamp there would be no need for separate put/get pointers.

It would also be necessary to store the bank ID if the rom being emulated were bank-switched, which would need an extra byte per saved fetch record.

The utility of this would depend on how much free internal RAM is in the SOC, but even something as low as 30K 16-bit words ought to be enough to record all behaviour during a single vectrex drawing cycle.

Some mechanism would be necessary to trigger the Vextreme to save the cyclic buffer to permanent storage.  Possible trigger mechanisms might include: 1) external signal to gpio pin 2) external signal via edge connector bus (eg nmi)  3) RPC call from 6809  4) trap on any access to a specific address  5) trap on any attempt to write to rom address space.

If the vextreme has sufficient memory available it would also be possible to implement an array which is the same size as the emulated rom memory, containing flags that could be used to trigger actions - eg trigger an action on read from any marked address, or have write protection at a byte address level in a writable cartridge, or trigger a 6809 interrupt on access to specific byte addresses.

The data logging of the execution path history would be extremely valuable to Vectrex developers because there is currently no other mechanism for tracing program execution that does not also interfere with that execution, whereas this would be like an external logic analyzer sniffing the bus and would not be visible from the 6809.

djmips, 2020-04-21:
I think this is a good idea.  As an aside, when I worked at Electronic Arts in the nineties, they made exactly such a thing for the SNES and I was able to use it to find some tricky timing bugs with the multiplication hardware and Mode 7.  It showed what was happening on every clock and was great for post mortem debugging since you could see how your code got off into the weeds.

technobly, 2020-05-26:
Thanks for the write up @gtoal !  I do agree this would be an amazing feature, even if it required a totally separate stripped down build of the STM32 code and only worked for 32KB games (so that there would be plenty of RAM for other things).

Another plan I have of getting similar tracing with not much cost, is a pass-through board that connects to two 16-bit logic analyzers.  With a little scripting and proper triggering, the saved data could be stitched back together to form a cheap 32-bit logic analyzer for the Vectrex.  You could easily stream as much as you wanted back to the computer via USB.

Even without the trace feature built into VEXTREME, I think the various traps on memory read/write or other hooks into /NMI /HALT would be valuable.  And the ability to dump the Vectrex's RAM would be good, although, you can currently do a lot of this in Vide as well with single stepping.  Where that breaks down is when you are trying to debug VEXTREME's operation with RPC calls and it's emulated ROM.  Because of this, I'm leaning more towards the LA approach because it would interfere less with the operation of VEXTREME.

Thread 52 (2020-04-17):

remove arbitrary timing loops

gtoal, 2020-04-17:
I'm not sure if this is really a bug report or an enhancement request;

Suggestion: use arm cycle count register for accurate short timings rather than timing loops which may be cache dependent.

    mov   r6,#10                // <- Oscillator frequency dependent magic number here!!
    waitdataloop:
    subs  r6,#1
    bne   waitdataloop

3.4.28. c15, Cycle Counter Register (CCNT)
The Cycle Counter Register counts the processor clock cycles. It is a 32-bit counter that can trigger an interrupt on overflow. You can use it in conjunction with the Performance Monitor Control Register and the two Counter Registers to provide a variety of useful metrics that enable you to optimize system performance.

You can access the Cycle Counter Register by reading or writing CP15 c15 with the Opcode_2 field set to 1:

MRC p15, 0, <Rd>, c15, c12, 1 ; Read Cycle Counter Register
MCR p15, 0, <Rd>, c15, c12, 1 ; Write Cycle Counter Register
The value in the Cycle Counter Register is Unpredictable at Reset. The counter can be set to zero by the Performance Monitor Control Register.

The Cycle Counter Register can be configured to count every 64th clock cycle by the Performance Monitor Control Register.

http://infocenter.arm.com/help/index.jsp?topic=/com.arm.doc.ddi0360f/BIHCGFCF.html

technobly, 2020-05-04:
I have recently disabled the Sys_Tick_Handler in favor of the DWT hardware cycle counter to do short timing and delays... so we are most of the way there :D   Cycle count is still oscillator dependent though, so I think these little magic timing values will always be an issue if we want the code to be tight.  The other way to do it is to create a hardware timer that is always set to something useful like 1us that gets clocked based on initial setup (reload value) and MCU oscillator value... but it still wouldn't be useful for the super tight timing delay you referenced above.

technobly, 2020-05-24:
Here's the appropriate ARM reference section for VEXTREME as well, Cortex-M4... and the section on DWT: http://infocenter.arm.com/help/index.jsp?topic=/com.arm.doc.100166_0001_04_en/ric1417175910926.html

technobly, 2020-05-26:
@gtoal good news!  This was resolved without weird timers... turns out the Vectrex gives us all of the timing info we need already, just have to monitor the right signals.  Fixed in PR #61 here: https://github.com/technobly/VEXTREME/pull/61/files#diff-d5f45277bf3d94a2cc5369b788f6ffdfR197-R203

Closed 2020-05-26.

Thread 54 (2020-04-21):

MAME Terminal

technobly, 2020-04-21:
The serial port on VEXTREME is a HW UART already on the STM32F4, running at 115200 baud.  It should be capable of being hooked up to DMA.  The idea here is that you'd map it to portion of memory that gets filled with vector lists via USB Serial or HW Serial to start, and the STM32 would drive the VIA directly with that list of vectors.

It would be cool to implement a simple POC that could move a ball around the screen or something like that via UART commands just to get an idea of how much overhead in CPU and UART timings we have before moving onto the full blown MAME Terminal support.

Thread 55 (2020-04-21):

High Score Save Interface

technobly, 2020-04-21:
We'd like to have a way to save high scores for each game, in an easy to maintain sort of way.  There are hooks for high score RAM location in the Vectrex BIOS that we can look at to see what the current high score is.

One way to attack this is to patch each game with the high score manager code, such that when the high score gets updated, the manager runs instead and allows for more custom things to be done.  This is kind of tedious to maintain though, and is anyone really going to trust high scores from an Open Source Vectrex Multicart? :D haha...

So how about we make this simpler and just give the owner of the cart a nice simple way to store the High Scores like this:
- Enable the High Score feature in the Options menu
- Play whatever game you want
- Assuming the high score has updated, press reset quickly (long reset returns to VEXTREME menu)
- VEXTREME swaps the game with the High Score save interface, and associates your score with the game in a SAVES.txt file.   Honor system here people!!
- There should also be a way to view High Scores for all games, within the interface... which could also be pulled up from the Options menu.

gtoal, 2020-05-04:
There are two ways to do this: 1) put a lot of work into finding where the high scores are held in each game; or 2) save the entire RAM and registers.. the latter would allow you to resume the game exactly where you left off.  Since the registers are not visible to the ARM in the cartridge, this would have to be done by simulating an interrupt and executing some code on the 6809 supplied by the vextreme.  Preferably in some spare address space and not the 48K supported by the cartridge (we do support 48K, yes, and not just 32K?)  All the code has to do is push any remaining registers, then transfer all ram to the cartridge via a RPC.  That ram dump would then be associated with that image, and restored when the image was loaded.  A bit of complicated shuffling would be necessary but it could be done.  And only has to be done once, rather than manually for every game.

technobly, 2020-05-04:
Hi @gtoal thanks for the ideas!  Did you see that @TylerBrymer has already implemented the first working version of this high score feature here #56 ?  It only saves known High Score BIOS location scores, but works automatically.

We have been discussing a Game Genie sort of feature that you describe there with the save/restore state.  That would definitely be interesting for a lot of reasons :D

VEXTREME supports up to 64KB with PB6 bank switching, and will eventually support 128KB bankswitching with /IRQ. See this feature request #25   Is there a weird 48KB middle ground support I don't know about?

gtoal, 2020-05-04:
Yes, there is nothing at all magic about 32K  The gap in the address space for eprom is 48K and I publicised this a couple of years ago, encouraging emulator writers to support it.  I can give you a 48K rom to test with; also Malban's new game (with 4 banks of rom) are 4 banks of 48K I believe.  Bloxorz may also be using 48K roms.

technobly, 2020-05-04:
I've tested Karl_Quappe_64 already which works, but that uses PB6 for A15.
Oh interesting... I honestly forgot about that unmapped space:
http://www.playvectrex.com/designit/chrissalo/memorymap.htm

Is there anything that needs to be done with /OE and /CE to make a `lda
$8000` work correctly?

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

gtoal, 2020-05-05:
Well, for a hardware solution, you have to properly decode the top bits of the address; for an emulator - just make sure the array is large enough. I posted a drawing when I wired up a cart once but can't immediately find it, probably quicker to re-engineer it from first principles.

gtoal, 2020-05-05:
PS There's actually 50K available but it might be better to keep that odd 2K spare for virtual peripherals or a DMA area or something.

Closed 2020-06-26.

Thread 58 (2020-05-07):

Menu repeats filenames when it finds a filename of 27 characters of more

technobly, 2020-05-07:
## Bug Report

### Expected Behavior

- Truncate filenames displayed to 16 characters
- Handle long filenames that don't exceed a 255 character path name without a problem
- Filenames that are in a path too long won't be displayed

### Observed Behavior

- The menu tries to print more than 19 characters off the edge of the screen
- Menu repeats filenames when it finds a filename of 27 characters of more even if they are in a path less than 255
- Long filename paths probably bug out...

### Steps to Reproduce

- Make some long filenames and paths and test

Closed 2020-05-29.

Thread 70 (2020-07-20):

Files and/or folders won't show up in the menu

Badummzi, 2020-07-20:
Hey technobly!

I recently sent you this issue via your e-mail, but since I think that you don't check it that often, I'll repost it here 😉 I hope that's ok!

Anyways, I'm having the following issue (from my e-mail):

I got my hands on a vextreme a few days ago, and now I've ran into an issue, that I have no idea how to fix...
I built and installed the firmware correctly, set up the menu successfully, after I had formatted the drive in windows with the correct settings. Everything seems to work just fine and I am also able to copy files onto the device.
However, i can't get anything other than the menu to work. I tried a lot of times in different ways, but the directory "roms" or any other never shows up in the menu. If I then press button 4 on the controller, the vectrex just crashes and if i reset the device, it goes to a buggy version of mine storm. What am I doing wrong? Could it be a fault on the pcb?

P.S. I had the cart plugged in the wrong way at first and the vectrex didn't boot at all, but after i flipped it everything worked fine (I hope that didn't do anything!) I also tried reformatting and cleaning the drive, creating a new partition and even reflashed the firmware, but to no avail. I'll put a video of me showing this problem as an attachment to this. Btw, I should also say, that I'm rocking a European Vectrex.

I hope that is something, that is easy to fix!

Since I'm not ably to upload mp4s here, I'm uploading it inside a zip-file.

[issue.zip](https://github.com/technobly/VEXTREME/files/4949530/issue.zip)

Thanks in advance! 😄

plasticbrain777, 2020-07-20:
Have you tried the latest compiled release from https://github.com/technobly/VEXTREME/releases/tag/v0.23

Badummzi, 2020-07-21:
@plasticbrain777 Thank you for your answer! :D But after extensive troubleshooting, I just realized, that I hadn't installed the right driver for windows 🙄 Now it works! ;)

Closed 2020-07-21.

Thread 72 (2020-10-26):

Be able to change LED-Brightness

Badummzi, 2020-10-26:
I'm currently using my Vextreme (btw, extremely happy with it!) without any casing and the only thing, which kind of annoys me, are the really bright leds facing upwards.

It would be a cool feature, to be able to reduce the led brightness, or turn it off completely!

Alternatively have a DIP switch on the pcb or another firmware, to turn them off?

technobly, 2020-10-27:
They are pretty bright without a case, and without a label.  If you want to perform a hacky way to dim them, you can open up [LED Test v2 app](https://github.com/technobly/VEXTREME/tree/master/code/led/led-test2) and turn down the brightness, then exit that test app and they should stay set to the same brightness until you power off.  We will be implementing some options that will persist to adjust things in the future.

Badummzi, 2020-10-30:
Oh, thank you! :D Not an ideal way, but this will work for now! ;)

Closed 2021-03-20.

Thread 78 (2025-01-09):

R4 and D3 swapped in B.Walach Hall-of-Fame build ?!

rwdavis3rd, 2025-01-09:
## Bug Report

### Expected Behavior

R4 and D3 parts appear to be swapped from their silk-screen-labeled positions in exemplary build.  Is this a intentional?   I saw in some version history that this diode's location was tweaked circa V0.2 (correct?)

### Observed Behavior

R4 and D3 parts appear to be swapped from their silk-screen-labeled positions in B.Walach Hall-of-Fame build, per illustration at
https://github.com/technobly/VEXTREME/blob/master/hall-of-fame/03%20-%20Brett%20Walach%20-%20v0.2/v0.2%20-%20top.jpg

### Steps to Reproduce

Note that the diode is illustrated in position R4 (per silk-screen) and the resistor populates position D3.   Other V0.2 builds (e.g. Malban) illustrate the parts populated as expected.   Since my (recent) build is not working, I thought I'd best clarify this detail... I'm pulling at threads because my (recent) V0.2 build is not healthy (Windows says it fails a Device Descriptor Test on attach...)

### References

Links to a video, or more info

technobly, 2025-08-11:
Thanks for the report, this is a bug in the silkscreen.  If you swap the parts, it will probably still work since they are in series, but you'll have to get the polarity of the LED correct.  If you build it like my image, that's the intended way.

This has been fixed in v1.0

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

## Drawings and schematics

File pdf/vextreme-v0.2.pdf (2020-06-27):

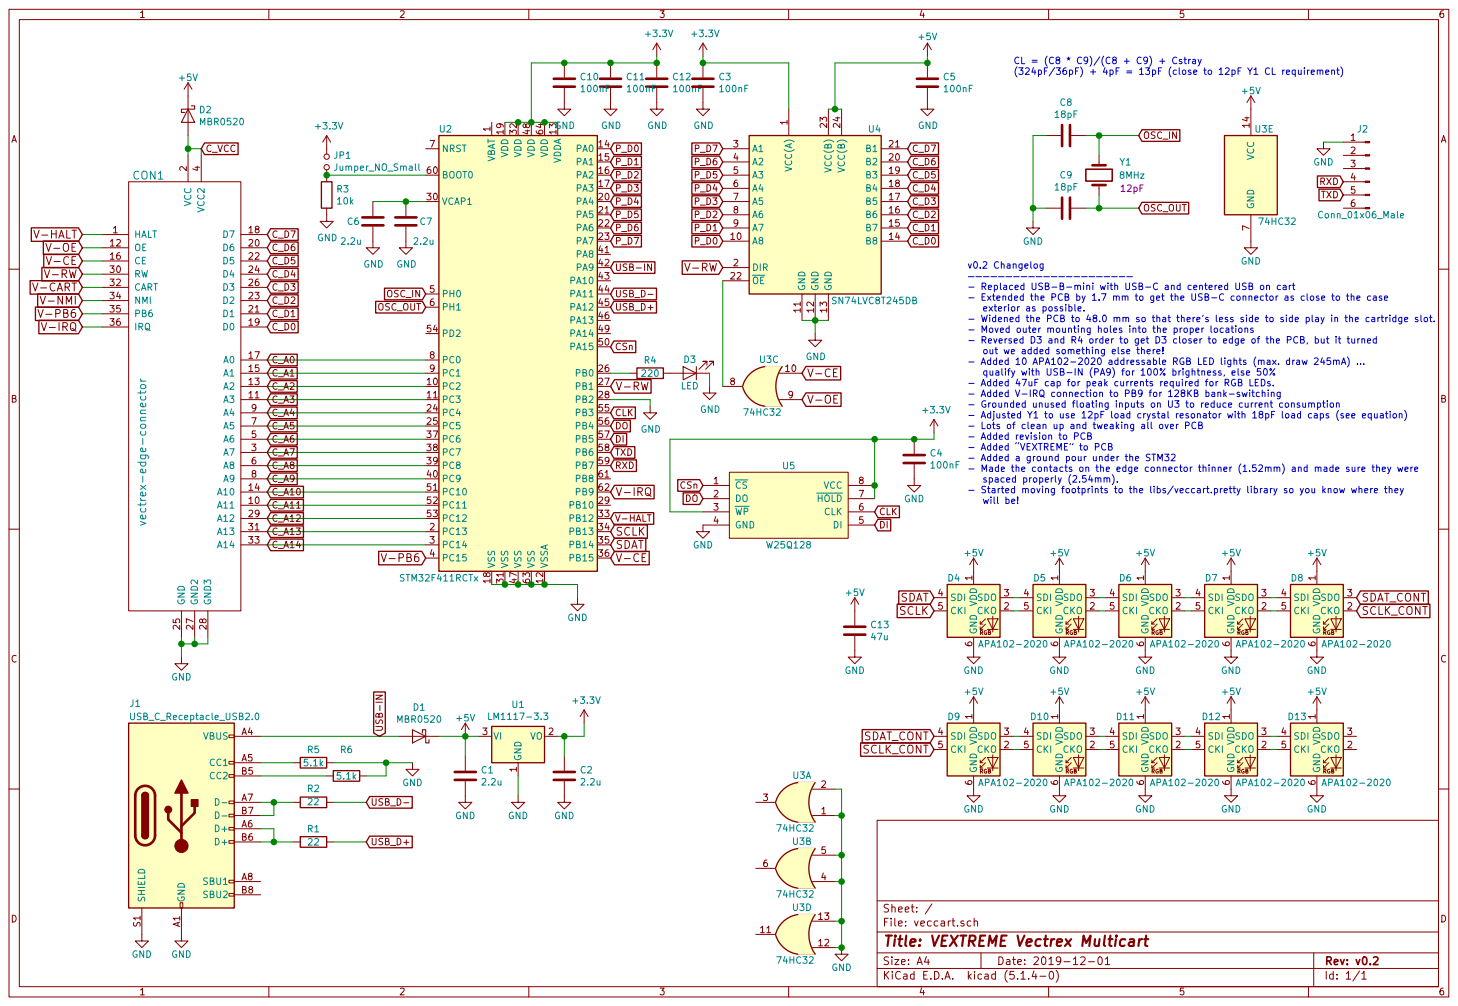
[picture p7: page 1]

1 VCAP1 30 VDD 19 VDD 32 VDD 48 VDD 64 VDDA 13 VSS 18 VSS 31 VSS 47 VSS 63 VSSA 12 U2 STM32F411RCTx VCC 14 GND

6 D13 APA102-2020 CS 1 DO 2 WP 3 GND 4 DI 5 CLK 6 HOLD 7 VCC 8 U5 W25Q128 VCC(A) 1 A8 10 GND 11 GND 12 GND 13 B8 14 B7 15 B6 16 B5 17 B4 18 B3 19 DIR 2 B2 20 B1 21 OE 22 VCC(B) 23 VCC(B) 24 A1 3 A2 4 A3 5 A4 6 A5 7 A6 8 A7 9 U4 SN74LVC8T245DB

2 D6 20 D1 21 D5 22 D2 23 D4 24 GND 25 D3 26 GND2 27 GND3 28 A12 29 A7 3 RW 30 A13 31 CART 32 A14 33 NMI 34 PB6 35

6 D4 APA102-2020 HALT 1 A11 10 A3 11 OE 12 A2 13 A10 14 A1 15 CE 16 A0 17 D7 18 D0 19 VCC

- Replaced USB-B-mini with USB-C and centered USB on cart
- Extended the PCB by 1.7 mm to get the USB-C connector as close to the case
exterior as possible.
- Widened the PCB to 48.0 mm so that theres less side to side play in the cartridge slot.
- Moved outer mounting holes into the proper locations
- Reversed D3 and R4 order to get D3 closer to edge of the PCB, but it turned
out we added something else there!
- Added 10 APA102-2020 addressable RGB LED lights (max. draw 245mA)
qualify with USB-IN (PA9) for 100% brightness, else 50%
- Added 47uF cap for peak currents required for RGB LEDs.
- Added V-IRQ connection to PB9 for 128KB bank-switching
- Grounded unused floating inputs on U3 to reduce current consumption
- Adjusted Y1 to use 12pF load crystal resonator with 18pF load caps (see equation)
- Lots of clean up and tweaking all over PCB
- Added revision to PCB
- Added VEXTREME to PCB
- Added a ground pour under the STM32
- Made the contacts on the edge connector thinner (1.52mm) and made sure they were
spaced properly (2.54mm).
- Started moving footprints to the libs/veccart.pretty library so you know where they
will be!

1 CKO 2 SDO 3 SDI 4 CKI 5 GND

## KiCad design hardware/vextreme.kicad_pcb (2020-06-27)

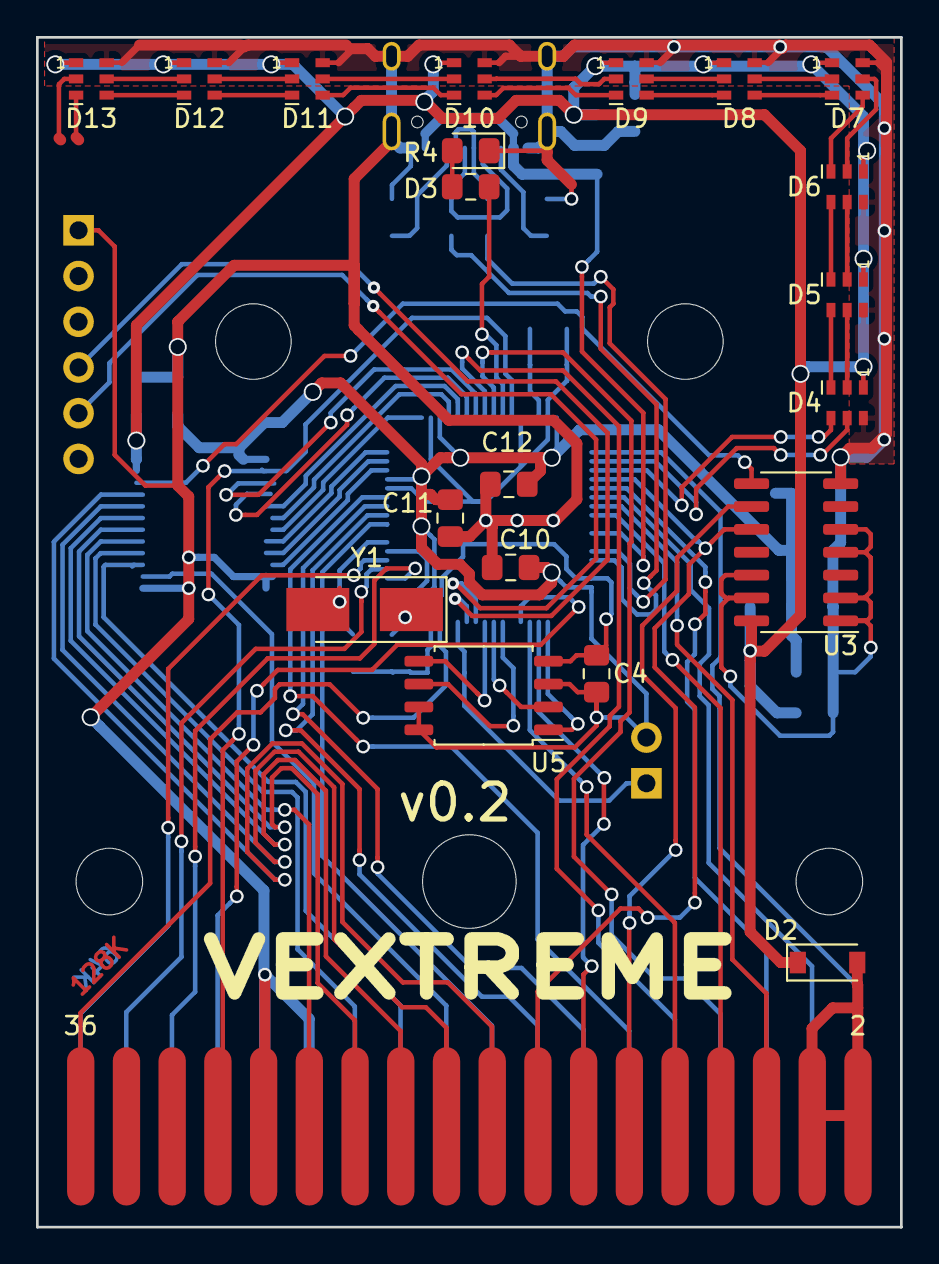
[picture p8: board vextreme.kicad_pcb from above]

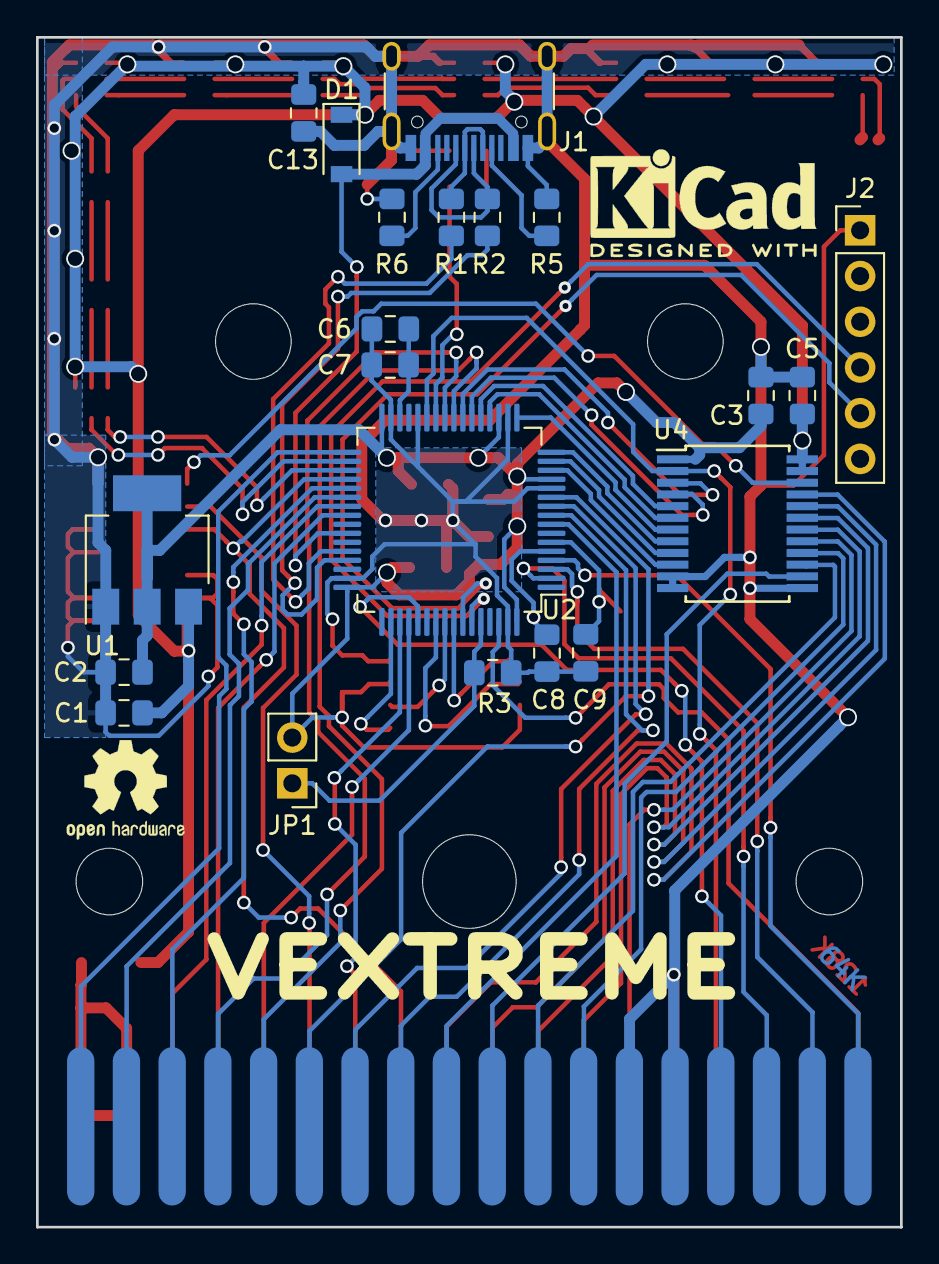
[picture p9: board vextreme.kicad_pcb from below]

Board: 2 copper layers, 48.0 x 66.1 mm, 47 parts (21 on the bottom side), 81 nets.

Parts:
C1, C2, C6, C7: 2.2u; C_0805_2012Metric_Pad1.15x1.40mm_HandSolder
C3, C4, C5, C10, C11, C12: 100nF; C_0805_2012Metric_Pad1.15x1.40mm_HandSolder
C8, C9: 18pF; C_0805_2012Metric_Pad1.15x1.40mm_HandSolder
C13: 47u; C_0805_2012Metric_Pad1.15x1.40mm_HandSolder
CON1: vectrex-edge-connector; vectrex-edge-connector-thinner-no-soldermask
D1, D2: MBR0520; D_SOD-123
D3: LED; LED_0805_2012Metric_Pad1.15x1.40mm_HandSolder
D4, D5, D6, D7, D8, D9, D10, D11, D12, D13: APA102-2020; LED-APA102-2020_6_REV_2
J1: USB_C_Receptacle_USB2.0; USB_C_Receptacle_HRO_TYPE-C-31-M-12
J2: Conn_01x06_Male; PinHeader_1x06_P2.54mm_Vertical
JP1: Jumper_NO_Small; PinHeader_1x02_P2.54mm_Vertical
R1, R2: 22; R_0805_2012Metric_Pad1.15x1.40mm_HandSolder
R3: 10k; R_0805_2012Metric_Pad1.15x1.40mm_HandSolder
R4: 220; R_0805_2012Metric_Pad1.15x1.40mm_HandSolder
R5, R6: 5.1k; R_0805_2012Metric_Pad1.15x1.40mm_HandSolder
U1: LM1117-3.3; SOT-223-3_TabPin2
U2: STM32F411RCTx; LQFP-64_10x10mm_P0.5mm
U3: 74HC32; SOIC-14_3.9x8.7mm_P1.27mm
U4: SN74LVC8T245DB; SSOP-24_5.3x8.2mm_P0.65mm
U5: W25Q128; SOIC-8_5.23x5.23mm_P1.27mm
Y1: 8MHz; Crystal_SMD_5032-2Pin_5.0x3.2mm_HandSoldering
hole1, hole3: Mounting_Hole_D3.7mm
hole2: Mounting_Hole_D5.2mm
hole4, hole5: Mounting_Hole_D4.2mm

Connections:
+3V3: C2.1, C3.1, C4.1, C10.1, C11.1, C12.1, JP1.2, U1.2, U2.13, U2.19, U2.32, U2.48, U2.64, U4.1, U5.3, U5.7, U5.8
+5V: C1.1, C5.1, C13.1, D1.1, D2.1, D4.1, D5.1, D6.1, D7.1, D8.1, D9.1, D10.1, D11.1, D12.1, D13.1, U1.3, U3.14, U4.23, U4.24
CLK: U2.55, U5.6
CSn: U2.50, U5.1
C_A0: CON1.17, U2.8
C_A1: CON1.15, U2.9
C_A2: CON1.13, U2.10
C_A3: CON1.11, U2.11
C_A4: CON1.9, U2.24
C_A5: CON1.7, U2.25
C_A6: CON1.5, U2.37
C_A7: CON1.3, U2.38
C_A8: CON1.6, U2.39
C_A9: CON1.8, U2.40
C_A10: CON1.14, U2.51
C_A11: CON1.10, U2.52
C_A12: CON1.29, U2.53
C_A13: CON1.31, U2.2
C_A14: CON1.33, U2.3
C_D0: CON1.19, U4.14
C_D1: CON1.21, U4.15
C_D2: CON1.23, U4.16
C_D3: CON1.26, U4.17
C_D4: CON1.24, U4.18
C_D5: CON1.22, U4.19
C_D6: CON1.20, U4.20
C_D7: CON1.18, U4.21
C_VCC: CON1.2, CON1.4, D2.2
DI: U2.57, U5.5
DO: U2.56, U5.2
GND: C1.2, C2.2, C3.2, C4.2, C5.2, C6.2, C7.2, C8.2, C9.2, C10.2, C11.2, C12.2, C13.2, CON1.25, CON1.27, CON1.28, D3.1, D4.6, D5.6, D6.6, D7.6, D8.6, D9.6, D10.6, D11.6, D12.6, D13.6, J1.A1, J1.A12, J1.B1, J1.B12, J1.S1, J2.1, R3.2, R5.1, R6.1, U1.1, U2.12, U2.18, U2.28, U2.31, U2.47, U2.63, U3.1, U3.2, U3.4, U3.5, U3.7, U3.12, U3.13, U4.11, U4.12, U4.13, U5.4
unnamed: C6.1, C7.1, U2.30
unnamed: D3.2, R4.1
unnamed: D4.2, D5.5
unnamed: D4.3, D5.4
unnamed: D5.2, D6.5
unnamed: D5.3, D6.4
unnamed: D6.2, D7.5
unnamed: D6.3, D7.4
unnamed: D7.2, D8.5
unnamed: D7.3, D8.4
unnamed: D10.2, D11.5
unnamed: D10.3, D11.4
unnamed: D9.3, D10.4
unnamed: D9.2, D10.5
unnamed: D11.2, D12.5
unnamed: D11.3, D12.4
unnamed: D12.2, D13.5
unnamed: D12.3, D13.4
unnamed: J1.A5, R5.2
unnamed: J1.A6, J1.B6, R1.2
unnamed: J1.A7, J1.B7, R2.1
unnamed: J1.B5, R6.2
unnamed: JP1.1, R3.1, U2.60
unnamed: R4.2, U2.26
unnamed: U3.8, U4.22
OSC_IN: C8.1, U2.5, Y1.1
OSC_OUT: C9.1, U2.6, Y1.2
P_D0: U2.14, U4.10
P_D1: U2.15, U4.9
P_D2: U2.16, U4.8
P_D3: U2.17, U4.7
P_D4: U2.20, U4.6
P_D5: U2.21, U4.5
P_D6: U2.22, U4.4
P_D7: U2.23, U4.3
RXD: J2.4, U2.59
SCLK: D4.5, U2.34
SCLK_CONT: D8.2, D9.5
SDAT: D4.4, U2.35
SDAT_CONT: D8.3, D9.4
TXD: J2.5, U2.58
USB-IN: D1.2, J1.A4, J1.A9, J1.B4, J1.B9, U2.42
USB_D+: R1.1, U2.45
USB_D-: R2.2, U2.44
V-CE: CON1.16, U2.36, U3.10
V-HALT: CON1.1, U2.33
V-IRQ: CON1.36, U2.62
V-OE: CON1.12, U3.9
V-PB6: CON1.35, U2.4
V-RW: CON1.30, U2.27, U4.2

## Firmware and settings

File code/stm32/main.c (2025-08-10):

/***************************************************************************
  Copyright (C) 2020 Brett Walach <technobly at gmail.com>
  --------------------------------------------------------------------------
  VEXTREME main.c

  The magic starts here!

  Original header follows:
  --------------------------------------------------------------------------
  Copyright (C) 2015 Jeroen Domburg <jeroen at spritesmods.com>

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
  You should have received a copy of the GNU Lesser General Public License
  along with this library.  If not, see <http://www.gnu.org/licenses/>.
  *************************************************************************/

#include <libopencm3/stm32/rcc.h>
#include <libopencm3/stm32/syscfg.h>
#include <libopencm3/stm32/gpio.h>
#include <libopencm3/stm32/usart.h>
#include <libopencm3/stm32/exti.h>
#include <libopencm3/cm3/nvic.h>
#include <libopencm3/stm32/pwr.h>
#include <libopencm3/stm32/flash.h>
#include <libopencm3/cm3/dwt.h>
#include <stdlib.h>
#include <string.h>

#include "sys.h"
#include "led.h"
#include "delay.h"
#include "main.h"
#include "menu.h"
#include "msc.h"
#include "highscore.h"
#include "settings.h"
// #include "flash.h"

//#include "rom.h"
#include "xprintf.h"
#include "fatfs/ff.h"

// Externs
extern GameFileRecord* pActiveGameData;
extern char menu_start;
extern char menu_end;

#define MENU_DATA_ADDR  (0x4000)                // fixed location in menu.bin
#define MENU_DATA_SIZE  (0x200)                 // size allocated for menu data
#define MENU_SYS_ADDR   (MENU_DATA_ADDR - 0x20) // 32 bytes reserved for system data (0x3BF0)
#define MENU_MEM_ADDR   (MENU_SYS_ADDR - 0x400) //  1k bytes reserved for settings data (0x3BC0)
#define PARM_RAM_ADDR   (0x7f00)
#define PARM_RAM_SIZE   (0xfe)

// Memory for the menu ROM and the running cartridge.
// We keep both in memory so we can quickly exchange them when a reset has been detected.
char menuData[20*1024]; // 16KB for menu ROM, 4KB for menu data
char* romData = menuData;
unsigned char parmRam[256];

char menuDir[_MAX_LFN + 1];
static bool isItemAFile = false; // Default to being a directory and not a file

static SettingsRecord settings = {0};
static bool settingsReady = false;

union cart_and_listing {
    dir_listing listing;
    char cartData[64*1024];
};

union cart_and_listing c_and_l;
char* cartData = c_and_l.cartData;

system_options sys_opt;
char* sysData = (char*)&sys_opt;
uint8_t checkDevMode = 0;

FILINFO cart_file_info;

/*
//Pinning:
A0-A14,SWCTL - PC0-PC15
D0-D7 - PA0-PA7
nWR - PB1
nCART - PB15
led - PB0
USBPWR - PA9
*/

#define SYSCFG_MEMRMP MMIO32(SYSCFG_BASE + 0x00)

// Local functions
static void doStartRom(void);

void uart_output_func(unsigned char c) {
    uint32_t reg;
    do {
        reg = USART_SR(USART1);
    } while ((reg & USART_SR_TXE) == 0);
    USART_DR(USART1) = (uint16_t) c & 0xff;
}

void applyLedSettings(bool initial) {
    uint8_t i = ledsNumPixels();
    uint8_t l = settings.led_luma * 8;
    uint32_t c = ((settings.led_red   * 8 + 7) << 16)
               | ((settings.led_green * 8 + 7) << 8)
               | ((settings.led_blue  * 8 + 7) << 0);

    switch (settings.led_mode)
    {
    case 0:  // off
        ledsClear();
        ledsUpdate();
        break;

    case 1:  // rainbow
        ledsSetBrightness(l);
        if (initial) {
            rainbowStep(4);
        }
        break;

    case 2:  // solid color
        ledsSetBrightness(l);
        while (i > 0) {
            ledsSetPixelColor(--i, c);
        }
        ledsUpdate();
        break;

    default:
        break;
    }
}

// ASM function
extern void romemu(void);

// Load a ROM into cartridge memory
void loadMenu() {
    bool use_embedded_menu = (f_stat("/menu.bin", &cart_file_info) != FR_OK);

    loadRomWithHighScore("/menu.bin", false, use_embedded_menu);
}

void loadRom(char *fn) {
    loadRomWithHighScore(fn, false, false); // by default, do not load high score mode
}

void loadRomWithHighScore(char *fn, bool load_hs_mode, bool use_embedded_menu) {
    const int SCORE_ADDR = MENU_SYS_ADDR + 0x10;
    FIL f;
    FRESULT fr = FR_NO_FILE; // assume no file, so we can test if we ever opened the file later
    unsigned int bytesRead = 0;
    int romDataSize = 0;
    if (romData == c_and_l.cartData) {
        // loaded cart data
        romDataSize = sizeof(c_and_l.cartData);
    } else {
        // loaded menu data
        romDataSize = sizeof(menuData);
    }
    if (romData == menuData && use_embedded_menu == true) {
        xprintf("Copying %lu bytes of menu data... ", &menu_end - &menu_start);
        memcpy(menuData, &menu_start, &menu_end - &menu_start);
        xprintf("OK!\n");
    } else {
        fr = f_open(&f, fn, FA_READ);
        if (fr) {
            xprintf("Error opening file: %d\n", fr);
        } else {
            xprintf("Opened file: %s\n", fn);
        }
        f_read(&f, romData, 64*1024, &bytesRead);
        xprintf("Read %d bytes of rom data.\n", bytesRead);
    }

    // It's a game
    if (romData != menuData) {
        unsigned int x;
        unsigned int maxCartSize;
        char swapByte;
        if (bytesRead <= 32*1024) {
            maxCartSize = 32*1024; // 32KB game
        } else {
            maxCartSize = 64*1024; // 64KB game
        }
        // pad with 0x01 for Mine Storm II and Polar Rescue (and any
        // other buggy game that reads outside its program space)
        for (x = bytesRead; x < maxCartSize; x++) {
            romData[x] = 0x01;
        }
        xprintf("Padded remaining %d bytes of rom data with 0x01\n", x - bytesRead);
        if (maxCartSize == 32*1024) {
            // Duplicate lower 32KB bank to upper 32KB bank, just for safety in case something in the 32KB game toggles PB6
            for (x = 0; x < maxCartSize; x++) {
                romData[(32*1024) + x] = romData[x];
            }
        } else {
            // Swap banks for 64KB games (copy upper 32KB bank to lower, and lower 32KB to upper)
            // This is because we invert PB6 in romemu.S:166 to make loading the menu a bit easier.
            for (x = 0; x < 32*1024; x++) {
                swapByte = romData[x];
                romData[x] = romData[(32*1024) + x];
                romData[(32*1024) + x] = swapByte;
            }
        }

        if (load_hs_mode) {
            // Search for game in highscore file and if it exists read it into
            // the active game high score record.  If the game doesn't exist,
            // then setup record to default values for high score and add the name.
            // A NULL as the second param will use the default active pointer.
            HighScoreRetVal hs_ret_val = highScoreGet((const unsigned char *)&romData[0x11], NULL);
            if (hs_ret_val != HIGH_SCORE_SUCCESS) {
                xprintf("highScoreGet failure: %d, creating default high score for: %s\n", hs_ret_val, fn);
                // Set the active game record to defaults and change name to the current
                // game we are loading. This will prepare it to be stored once we
                // acquire a new high score from the game ROM running.
                hs_ret_val = highScoreSetGameRecordToDefaults((const unsigned char *)&romData[0x11], NULL);
                if (hs_ret_val != HIGH_SCORE_SUCCESS) {
                    xprintf("highScoreSetGameRecordToDefaults failure: %d\n", hs_ret_val);
                }
            } else {
                xprintf("highScoreGet success\n");
            }

            // Store high score towards the end of the menu data
            menuData[SCORE_ADDR + 0x00] = pActiveGameData->maxScore[0];
            menuData[SCORE_ADDR + 0x01] = pActiveGameData->maxScore[1];
            menuData[SCORE_ADDR + 0x02] = pActiveGameData->maxScore[2];
            menuData[SCORE_ADDR + 0x03] = pActiveGameData->maxScore[3];
            menuData[SCORE_ADDR + 0x04] = pActiveGameData->maxScore[4];
            menuData[SCORE_ADDR + 0x05] = pActiveGameData->maxScore[5];
            menuData[SCORE_ADDR + 0x06] = 0x80;
            menuData[MENU_SYS_ADDR] = 0x77; // High Score flag (IDLE:0x66, LOAD2VEC:0x77, SAVE2STM:0x88)
            // parmRam[0xe0] = 0x77; // High Score flag (IDLE:0x66, LOAD2VEC:0x77, SAVE2STM:0x88)

            // Don't start game yet, stay in menu so that the VEXTREME menu
            // can read and store the high score
            romData = menuData;
        } // end if (load_hs_mode)
    }
    // It's the menu, patch in the HW/SW versions
    else {
        char* ptr1 = strstr(menuData, "11");
        char* ptr2 = strstr(menuData, "22");
        char* ptr3 = strstr(menuData, "33");
        char* ptr4 = strstr(menuData, "44");
        if (ptr1 && ptr2 && ptr3 && ptr4) {
            *ptr1++ = 'V';
            *ptr1   = '0' + (sys_opt.hw_ver >> 8) % 10;
            *ptr2++ = '0' + (sys_opt.hw_ver & 0xFF) / 10;
            *ptr2   = '0' + (sys_opt.hw_ver & 0xFF) % 10;
            *ptr3++ = 'V';
            *ptr3   = '0' + (sys_opt.sw_ver >> 8) % 10;
            *ptr4++ = '0' + (sys_opt.sw_ver & 0xFF) / 10;
            *ptr4   = '0' + (sys_opt.sw_ver & 0xFF) % 10;
        }
        // if (load_hs_mode) {
        //  // parmRam[0xe0] = 0x66; // High Score flag (IDLE:0x66, LOAD2VEC:0x77, SAVE2STM:0x88)
        //  menuData[MENU_SYS_ADDR] = 0x66;
        // }

        if (settingsReady) {
            xprintf("Copying %lu bytes of settings data... ", sizeof(SettingsRecord));
            // copy setting to ROM
            memcpy(&menuData[MENU_MEM_ADDR], &settings, sizeof(SettingsRecord));
            xprintf("OK!\n");
        }
    }

    if (fr != FR_NO_FILE) {
        f_close(&f);
    }
}

//Stream data, for the Bad Apple demo
//Name of the file sucks and I'd like to make a rpc function that's a bit
//more universal... you should eg be able to pass through the name of the
//file you'd like to stream and the address and chunk size... but this is
//a start.
FIL streamFile;
int streamLoaded=0;

void loadStreamData(int addr, int len) {
    UINT r=0;
    if (!streamLoaded) {
        f_open(&streamFile, "vec.bin", FA_READ);
        streamLoaded=1;
    }
    f_read(&streamFile, &romData[addr], len, &r);
}

void doUpDir() {
    if (strcmp(menuDir, "/roms") != 0) {
        doChangeDir("..");
    }
}

void doChangeDir(char* dirname) {
    xprintf("Found directory: %s\n", dirname);
    if (strcmp(dirname,"..") == 0) {
        char* ptr = strrchr(menuDir,'/');
        if (ptr != NULL) {
            *ptr = '\0';
        }
    } else {
        xsprintf(menuDir, "%s/%s", menuDir, dirname);
    }

    romData=menuData;
    loadListing(menuDir, &c_and_l.listing, MENU_DATA_ADDR,
                MENU_DATA_ADDR + MENU_DATA_SIZE, romData);

    xprintf("Done listing for : %s\n", menuDir);

    // save current directory and reset cursor
    settings.last_cursor = 0;
    strncpy(settings.directory, menuDir, sizeof(menuDir));
    syncSettings();
}

void syncSettings() {
    memcpy(&menuData[MENU_MEM_ADDR], &settings, sizeof(SettingsRecord));
    settingsSave(&settings);
}

/**
 * User has made a selection in the cart menu (chose the i'th item)
 * so now we have to load the ROM or Directory
 */
void doChangeRom(char* basedir, int i) {
    char buff[300];

    xprintf("Changing to rom no %d in %s\n", i, basedir);
    sortDirectory(basedir, &c_and_l.listing); // recreate file listing, as loading a cart overwrote the union
    file_entry f = c_and_l.listing.f_entry[i];

    if (f.is_dir) {
        isItemAFile = false;
        doChangeDir(f.fname);
    } else {
        isItemAFile = true;
        xprintf("Adding filename [%s] to path\n", f.fname);
        xsprintf(buff, "%s/%s", basedir, f.fname);

        // save current cursor position selection
        settings.last_cursor = i;
        syncSettings();

        romData=c_and_l.cartData;
        xprintf("Going to read rom image %s\n", buff);
        loadRomWithHighScore(buff, true, false);
    }


}

/**
 * Point romData to the cartData or menuData based on what was last loaded
 * in doChangeRom() and return.
 */
static void doStartRom(void) {
    if (isItemAFile == true) {
        romData = c_and_l.cartData;
    } else {
        romData = menuData;
    }
}

void updateAll() {
    uint16_t i = ledsNumPixels();
    while (i > 0) {                     // color index
        ledsSetPixelColor(--i, colors[(int)parmRam[254]]);
    }
    ledsUpdate();
}

void updateOne() {
    //                led index        , color index
    ledsSetPixelColor((int)parmRam[253], colors[(int)parmRam[254]]);
    ledsUpdate();
}

void updateMulti() {
    // uint16_t i = ledsNumPixels();
    for (uint16_t i = 0; i < ledsNumPixels(); i++) {
        // xprintf("LED%d = %d\n", i, (int)parmRam[0xf0 + i]);
        ledsSetPixelColor(i, colors[(int)parmRam[0xf0 + i]]); // 0xf0 = LED0, 0xf9 = LED9
    }
    // xprintf("\n");
    ledsUpdate();
}

void doLedOn(int on) {
    if (on) {
        gpio_set(GPIOB, GPIO0);
    } else {
        gpio_clear(GPIOB, GPIO0);
    }
}

// This function to be used by games (cartData)
// Load HW/SW versions so that the menu can access and display them
// Warning: This permanently alters the last 4 bytes of 32K ROM game data!
void loadVersions() {
    c_and_l.cartData[0x7ffc] = sys_opt.hw_ver >> 8;
    c_and_l.cartData[0x7ffd] = sys_opt.hw_ver & 0xFF;
    c_and_l.cartData[0x7ffe] = sys_opt.sw_ver >> 8;
    c_and_l.cartData[0x7fff] = sys_opt.sw_ver & 0xFF;
}

// This function to be used by the Menu (multcart.asm)
// Load sys_opt data starting at address specified, up to 15 bytes specified by size.
// addr = $7ffd
// size = $7ffe
// data returned in $3ffa ~ $3ffa+size
void loadSysOpt() {
    int addr = (int)parmRam[0xfd];
    int size = (int)parmRam[0xfe];
    if (size > 15) size = 15; // limited to 15 for now
    for (int i = 0; i < size; i++) {
        menuData[MENU_SYS_ADDR + 0x1a + i] = sysData[addr + i];
        // xprintf("sysData[%x]=%u,checkDevMode=%d\n", addr + i, sysData[addr + i], checkDevMode);
    }
}

// This function to be used by the Menu (multcart.asm)
// Load parmRam data starting at address specified, up to 15 bytes specified by size.
// addr = $7ffd
// size = $7ffe
// data returned in $3fe0 ~ $3fe0+size
void loadParmRam() {
    int addr = (int)parmRam[0xfd];
    int size = (int)parmRam[0xfe];
    if (size > 15) size = 15; // limited to 15 for now
    for (int i = 0; i < size; i++) {
        menuData[MENU_SYS_ADDR + i] = parmRam[addr + i];
        // xprintf("parmRam[%x]=%u\n", addr + i, parmRam[addr + i]);
    }
}
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
int main(void) {
    void (*runptr)(void)=romemu;

    const struct rcc_clock_scale hse_8mhz_3v3_120MHz = { /* 120MHz */
        .pllm = 8,
        .plln = 240,
        .pllp = 2,
        .pllq = 5,
        .pllr = 0,
        .pll_source = RCC_CFGR_PLLSRC_HSE_CLK,
        .hpre = RCC_CFGR_HPRE_DIV_NONE,
        .ppre1 = RCC_CFGR_PPRE_DIV_4,
        .ppre2 = RCC_CFGR_PPRE_DIV_2,
        .voltage_scale = PWR_SCALE1,
        .flash_config = FLASH_ACR_ICEN | FLASH_ACR_DCEN | FLASH_ACR_LATENCY_3WS,
        .ahb_frequency  = 120000000,
        .apb1_frequency = 30000000,
        .apb2_frequency = 60000000,
    };

    rcc_clock_setup_pll(&hse_8mhz_3v3_120MHz);
    rcc_periph_clock_enable(RCC_GPIOA);
    rcc_periph_clock_enable(RCC_GPIOB);
    rcc_periph_clock_enable(RCC_GPIOC);
    rcc_periph_clock_enable(RCC_USART1);
    rcc_periph_clock_enable(RCC_SYSCFG);

    //Addressable LEDs - output
    gpio_mode_setup(GPIOB, GPIO_MODE_OUTPUT, GPIO_PUPD_NONE, GPIO13 | GPIO14);
    // gpio_set_output_options(GPIOB, GPIO_OTYPE_PP, GPIO_OSPEED_2MHZ,  GPIO13 | GPIO14);
    //LED - output
    gpio_mode_setup(GPIOB, GPIO_MODE_OUTPUT, GPIO_PUPD_NONE, GPIO0);
    //USB power - input
    gpio_mode_setup(GPIOA, GPIO_MODE_INPUT, GPIO_PUPD_PULLDOWN, GPIO9);

    //PB6/PB7: txd/rxd
    gpio_mode_setup(GPIOB, GPIO_MODE_AF, GPIO_PUPD_NONE, GPIO6 | GPIO7);
    gpio_set_af(GPIOB, GPIO_AF7, GPIO6 | GPIO7);

    usart_set_baudrate(USART1, 115200);
    usart_set_databits(USART1, 8);
    usart_set_stopbits(USART1, USART_STOPBITS_1);
    usart_set_mode(USART1, USART_MODE_TX);
    usart_set_parity(USART1, USART_PARITY_NONE);
    usart_set_flow_control(USART1, USART_FLOWCONTROL_NONE);
    /* Finally enable the USART. */
    usart_enable(USART1);
    xdev_out(uart_output_func);

    //Address lines - input (A0 - A14 & PB6)
    gpio_mode_setup(GPIOC, GPIO_MODE_INPUT, GPIO_PUPD_PULLDOWN,
        GPIO0|GPIO1|GPIO2|GPIO3|GPIO4|GPIO5|GPIO6|GPIO7|GPIO8|GPIO9|GPIO10|GPIO11|GPIO12|GPIO13|GPIO14|GPIO15);
    // gpio_mode_setup(GPIOB, GPIO_MODE_INPUT, GPIO_PUPD_NONE,
    //  GPIO13|GPIO14);
    // IRQ
    gpio_mode_setup(GPIOB, GPIO_MODE_INPUT, GPIO_PUPD_NONE, GPIO9);

    //Data lines - output
    gpio_mode_setup(GPIOA, GPIO_MODE_OUTPUT, GPIO_PUPD_NONE,
        GPIO0|GPIO1|GPIO2|GPIO3|GPIO4|GPIO5|GPIO6|GPIO7);

    //Control lines - input
    gpio_mode_setup(GPIOB, GPIO_MODE_INPUT, GPIO_PUPD_NONE,
        GPIO1|GPIO15);

    // dwt_enable_cycle_counter required for delay/millis
    // used instead of systick_handler to prevent interrupts from disrupting romemu.S loop
    dwt_enable_cycle_counter();

#if HW_VER == 255
    #error "USE_HW hardware version not specified, please specify e.g. USE_HW=v0.2 or USE_HW=v0.3"
#endif

    // TODO: load new options from VEXTREME/options.txt in key=val format
    sys_opt.size = sizeof(sys_opt);
    sys_opt.ver = 1;
// #if (HW_VER == 1)
//  sys_opt.hw_ver = 0x000A; // v0.10
// #elif (HW_VER == 2)
//  sys_opt.hw_ver = 0x0014; // v0.20
// #elif (HW_VER == 3)
//  sys_opt.hw_ver = 0x001e; // v0.30
// #endif
    // For now, this is hard coded to determine LED operation, nothing more.
    // TODO: uncomment above for system hw_ver, and add .led_hw_ver for LED initialization.
    sys_opt.hw_ver = 0x0014; // v0.20
    sys_opt.sw_ver = 0x0028; // v0.40
    sys_opt.rgb_type = RGB_TYPE_10;
    sys_opt.usb_dev = USB_DEV_DISABLED;

    xprintf("\n");
    xprintf("[ VEXTREME booted ]\n");
    xprintf("  HW v%01d.%02d | SW v%01d.%02d\n", sys_opt.hw_ver >> 8, sys_opt.hw_ver & 0xFF, sys_opt.sw_ver >> 8, sys_opt.sw_ver & 0xFF);
    xprintf("  LED TYPE: ");
    // HW version < 0.30
    if (sys_opt.hw_ver < 0x001e) {
        // xprintf("HW VER < 0.30\n");
        if (sys_opt.rgb_type == RGB_TYPE_10) {
            xprintf("RGB_TYPE_10\n");
            ledsInitSW(10, GPIOB, GPIO14, GPIOB, GPIO13, RGB_BGR);
            ledsSetBrightness(50); // be careful not to set this too high when using white, those LEDs draw some power!!
        } else if (sys_opt.rgb_type == RGB_TYPE_4) {
            xprintf("RGB_TYPE_4\n");
            ledsInitSW(10, GPIOB, GPIO14, GPIOB, GPIO13, RGB_BGR);
            ledsSetBrightness(255); // we will be limiting to 4, it's ok to crank them all of the way up!
        } else if (sys_opt.rgb_type == RGB_TYPE_NONE) {
            xprintf("RGB_TYPE_NONE\n");
            ledsInitSW(10, GPIOB, GPIO14, GPIOB, GPIO13, RGB_BGR);
            ledsSetBrightness(0); // sleeper cart, you'll never see it coming _._
        }
    }
    // HW version >= 0.30
    else if (sys_opt.hw_ver >= 0x001e) { // >= 0.30
        // xprintf("HW VER >= 0.30\n");
        xprintf("type ignored, we only have 4!\n");
        ledsInitSW(4, GPIOB, GPIO14, GPIOB, GPIO13, RGB_BGR);
        ledsSetBrightness(255); // we will be limiting to 4, it's ok to crank them all of the way up!
    }

#if 0 // TEST LED CODE START
    while (1) {
        // color wipe back and fourth through the list of colors
        ledsClear();
        ledsSetBrightness(150);
        bool dir = true;
        for (int x = 1; x < sizeof(colors)/sizeof(*colors); x++) {
            colorWipe(dir, colors[x], 50);
            dir = !dir;
        }

        ledsClear();
        ledsSetBrightness(255);
        rainbowCycle(10);
        rainbowCycle(10);

        ledsClear();
        knightRider(6, 64, 4, 3, 9, 0xFF7700); // Cycles, Speed, Width, First, Last, RGB Color (original orange-red)
        knightRider(3, 32, 4, 3, 9, 0xFF00FF); // Cycles, Speed, Width, First, Last, RGB Color (purple)
        knightRider(3, 32, 4, 3, 9, 0x0000FF); // Cycles, Speed, Width, First, Last, RGB Color (blue)
        knightRider(3, 32, 5, 3, 9, 0x00FF00); // Cycles, Speed, Width, First, Last, RGB Color (green)
        knightRider(3, 32, 5, 3, 9, 0xFFFF00); // Cycles, Speed, Width, First, Last, RGB Color (yellow)
        knightRider(3, 32, 7, 3, 9, 0x00FFFF); // Cycles, Speed, Width, First, Last, RGB Color (cyan)
        knightRider(3, 32, 7, 3, 9, 0xFFFFFF); // Cycles, Speed, Width, First, Last, RGB Color (white)

        // Iterate through a whole rainbow of colors
        for(uint8_t j=0; j<252; j+=7) {
            knightRider(1, 16, 2, 0, 10, colorWheel(j)); // Cycles, Speed, Width, RGB Color
        }

        ledsClear();
        ledsSetBrightness(255);
        int y = 10;
        for (int x=0; x<10; x++) {
            theaterChaseRainbow(y);
            y += 5;
        }
    }
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

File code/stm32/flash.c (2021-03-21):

/*
 *  Copyright (C) 2015 Jeroen Domburg <jeroen at spritesmods.com>
 *
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
 * You should have received a copy of the GNU Lesser General Public License
 * along with this library.  If not, see <http://www.gnu.org/licenses/>.
 */
#include <stdlib.h>

#include <libopencm3/stm32/rcc.h>
#include <libopencm3/stm32/gpio.h>
#include <libopencm3/stm32/spi.h>
#include <libopencm3/usb/usbd.h>
#include <libopencm3/usb/msc.h>
#include <libopencm3/cm3/nvic.h>
#include <libopencm3/cm3/systick.h>
#include "flash.h"
#include "xprintf.h"

static volatile uint32_t flashBlkAge;
static uint8_t flashBlkData[4096];
static int flashBlkAddr=-1;

// SPI flash - W25Q128VF
// CS -  50 - PA15 - SPI1_NSS
// DO -  56 - PB4  - SPI1_MISO
// CLK - 55 - PB3  - SPI1_SCK
// DI -  57 - PB5  - SPI1_MOSI
// This flash has 4K sectors, divided in 256-byte pages.
// This means that if we write a (512-byte) sector, we need to
// read the 4k sector, erase it, modify the 512 bytes in the RAM
// buffer, then write the buffer back to the recently-erased sector.

// We actually do some caching here: as soon as the first 512-byte sector
// of a 4K page is written, we read the 4K sector into RAM and modify the RAM
// buffer to reflect the 512byte write. We don't write it back yet, there may
// be more writes incoming. If they do, we again modify the in-memory page. If
// there's a write to a different page or if 300ms seconds have passed, we
// write back the in-RAM page.

// To be called every 50th of a second
void flashTick() {
    flashBlkAge++;
    if (flashBlkAddr!=-1 && flashBlkAge>15) {
        flashDoWriteback();
        xprintf("Auto writeback after timeout\n");

        // We arrive here after each file copied to the cart or when the mounted drive is ejected.
    }
}

static void flashCs(int i) {
    if (i) gpio_set(GPIOA, GPIO15); else gpio_clear(GPIOA, GPIO15);
}

__attribute__((unused))
static void flashEraseChip(void) {
    int status;
    xprintf("Erasing chip...\n");
    //Send write enable
    flashCs(0);
    spi_xfer(SPI1, 6);
    flashCs(1);

    //Erase block
    flashCs(0);
    spi_xfer(SPI1, 0xc7); //chip erase
    flashCs(1);

    //Wait till erase is done
    do {
        flashCs(0);
        spi_xfer(SPI1, 5); //read status 1
        status=spi_xfer(SPI1, 0);
        flashCs(1);
    } while (status&1);
    xprintf("Erasing chip done.\n");
}

void flashInit(void) {
    static bool flash_init = false; // only allow flash to be initialized once
    if (flash_init) {
        return;
    }
    flash_init = true;

    int id, mf;
    gpio_mode_setup(GPIOA, GPIO_MODE_OUTPUT, GPIO_PUPD_NONE, GPIO15);
    gpio_mode_setup(GPIOB, GPIO_MODE_AF, GPIO_PUPD_NONE,
            GPIO3 | GPIO4 | GPIO5);
    gpio_set_af(GPIOB, GPIO_AF5, GPIO3 | GPIO4 | GPIO5);

    rcc_periph_clock_enable(RCC_SPI1);
    SPI1_I2SCFGR = 0;
    spi_init_master(SPI1, SPI_CR1_BAUDRATE_FPCLK_DIV_2, SPI_CR1_CPOL_CLK_TO_0_WHEN_IDLE, SPI_CR1_CPHA_CLK_TRANSITION_1, 
        SPI_CR1_DFF_8BIT,SPI_CR1_MSBFIRST);
    spi_enable_software_slave_management(SPI1);
    spi_set_nss_high(SPI1);
    spi_enable(SPI1);
    //Wait till SPI chip has started working
    do {
        flashCs(0);
        spi_xfer(SPI1, 0x90);
        spi_xfer(SPI1, 0);
        spi_xfer(SPI1, 0);
        spi_xfer(SPI1, 0);
        mf=spi_xfer(SPI1, 0);
        id=spi_xfer(SPI1, 0);
        flashCs(1);
    } while (mf==0 || mf==0xff || id==0 || id==0xff);
    xprintf("Flash inited (id/mf %x/%x).\n", id, mf);

    // Maybe you need to uncomment this to recover your SPI flash from being corrupted :)
    // flashEraseChip();
}


void flashDoWriteback() {
    int x, i, status;
    if (flashBlkAddr==-1) return;
    xprintf("Doing writeback on blk addr %x\n", flashBlkAddr);

//  printf("Writeback data:\n");
//  for (x=0; x<4096; x+=32) put_dump(flashBlkData+x, flashBlkAddr+x, 32, DW_CHAR);

    //Send write enable
    flashCs(0);
    spi_xfer(SPI1, 6);
    flashCs(1);

    //Erase block
    flashCs(0);
    spi_xfer(SPI1, 0x20); //sector erase
    spi_xfer(SPI1, (flashBlkAddr>>16)&0xff);
    spi_xfer(SPI1, (flashBlkAddr>>8)&0xff);
    spi_xfer(SPI1, (flashBlkAddr)&0xff);
    flashCs(1);

    //Wait till erase is done
    do {
        flashCs(0);
        spi_xfer(SPI1, 5); //read status 1
        status=spi_xfer(SPI1, 0);
        flashCs(1);
    } while (status&1);
//  xprintf("Blk erased.\n");

    //Write blocks
    for (i=0; i<4096; i+=256) {
        //Send write enable
        flashCs(0);
        spi_xfer(SPI1, 6);
        flashCs(1);

        //Send sector
        flashCs(0);
        spi_xfer(SPI1, 0x2); //page program
        spi_xfer(SPI1, (flashBlkAddr>>16)&0xff);
        spi_xfer(SPI1, (flashBlkAddr>>8)&0xff);
        spi_xfer(SPI1, (flashBlkAddr)&0xff);
        for (x=0; x<256; x++) {
            spi_xfer(SPI1, flashBlkData[x+i]);
        }
        flashCs(1);

        //Wait till write is done
        do {
            flashCs(0);
            spi_xfer(SPI1, 5); //read status 1
            status=spi_xfer(SPI1, 0);
            flashCs(1);
        } while (status&1);

        flashBlkAddr+=256;
    }
//  xprintf("Blk written.\n");
    gpio_clear(GPIOB, GPIO0); //turn off LED

    flashBlkAddr=-1;
}

int flashReadBlk(uint32_t lba, uint8_t *copy_to) {
    uint32_t addr=(lba*512);
    int x;
//  xprintf("Read LBA %d\n", lba);
    flashDoWriteback();
    flashCs(0);
    spi_xfer(SPI1, 0x0B); //fast read
    spi_xfer(SPI1, (addr>>16)&0xff);
    spi_xfer(SPI1, (addr>>8)&0xff);
    spi_xfer(SPI1, (addr)&0xff);
    spi_xfer(SPI1, 0); //dummy
    for (x=0; x<512; x++) copy_to[x]=spi_xfer(SPI1, 0);
    flashCs(1);
    return 0;
}

int flashWriteBlk(uint32_t lba, const uint8_t *copy_from) {
    uint32_t addr=(lba*512);
    uint32_t blkaddr=addr&(~4095);
    int x;

//  xprintf("Write to LBA %d addr %x:\n", lba, addr);
//  for (x=0; x<512; x+=32) put_dump(copy_from+x, addr+x, 32, DW_CHAR);


//  xprintf("Write lba %d (addr %x blkaddr %x)\n", lba, addr, blkaddr);

    if (blkaddr != (uint32_t)flashBlkAddr) {
        //Write back data in block cache, if any
        flashDoWriteback();
        gpio_set(GPIOB, GPIO0); //turn on LED
        //Read orig data into block cache
        flashCs(0);
        spi_xfer(SPI1, 0x0B); //fast read
        spi_xfer(SPI1, (blkaddr>>16)&0xff);
        spi_xfer(SPI1, (blkaddr>>8)&0xff);
        spi_xfer(SPI1, (blkaddr)&0xff);
        spi_xfer(SPI1, 0); //dummy
        for (x=0; x<4096; x++) flashBlkData[x]=spi_xfer(SPI1, 0);
        flashCs(1);

        flashBlkAddr=blkaddr;
    }

    //Modify data to reflect new sector
//  xprintf("Modifying block buffer for %x at %x\n", flashBlkAddr, (addr&(7<<9)));
    for (x=0; x<512; x++) {
        flashBlkData[x+(addr&(7<<9))]=copy_from[x];
    }
    flashBlkAge=0;

    return 0;
}

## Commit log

2020-06-27 rename 'veccart' to 'stm32' for firmware and 'vextreme' for hardware, rename 'multicart' to 'menu'.
    [vextreme-v0.2-B_Cu.gbl, vextreme-v0.2-B_Mask.gbs, vextreme-v0.2-B_Paste.gbp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]
2020-12-12 updated Hall of Fame
2021-03-06 Replace strcpy by strncpy
    [main.c]
2021-03-13 remove rescue library and merge all schematic parts into a common vextreme.lib
    [vextreme.sch]
2021-03-19 Fix LED brightness in solid color mode
    [main.c]
2021-03-19 Fix LED color component calculation so it can reach 255
    [main.c]
2021-06-19 New stm32 build container
    * Alpine-based
    * Uses latest official ARM toolchain (arm-none-eabi-gcc 10.2)
    * Add uf2conv.py and some make targets for supporting UF2 builds
2023-08-21 remove herobrine
    [vextreme-v0.2-B_Cu.gbl, vextreme-v0.2-B_Mask.gbs, vextreme-v0.2-B_Paste.gbp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]
2025-08-10 fixes #38, 64kb bankswitched games work now
    [main.c]
2025-08-26 reduce LED brightness by default, and let SETTINGS control
2025-08-26 tony case changes
2025-09-05 some changes to support 10 LED vs. 4 LED VEXTREMEs, halt line easter egg
2026-10-25 v0.3 Hardware Changes
    - moved vextreme symbol library into libs/ folder
    - renaming 'veccart' to 'vextreme' for hardware files
    - Generate v0.3 gerbers, pdf and BOM
    - Finish routing v0.3 PCB
    - Fixes #21, added VEXTREME logo to PCB
    - Also moved most components to the bottom side and unrouted to prepare for single-sided conversion
    - Fixes #18, Add ESD protection to USB
    - Fixes #36, add test points for power rails. Also add VEC-5V to PA10 to detect when Vectrex is on/off
    - Fixes #15, replace U3 with a single OR gate and add optional R7 to omit U3 completely
    - add SW1 for programming, add SW2 for STM32 reset
    - adds 3-pin header for LED output
    - Fixe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
2026-10-25 v0.4 Hardware Changes
    - Increased length of SW2 to 12mm (TS-1002S-12026C)
    - Changed SW1 to be the same as SW2
    - Replaced J2 & J3 with a single 2x3 header that presses into place and holds
    itself for soldering. Can use two separate 1x3 headers if desired.
    - Replaced JP1 with a 1x2 header that presses into place for soldering.
    - Added a micro 10-pin JTAG debugging header that doubles as USB Serial
    adapter as well.
    - Added a solderable jumper on V-NMI to be connected to one of PA8, which
    also can be optionally connected to SW2.
    - Added a diode for reverse polarity (cart upside down) on VEC_5V detect line. - Added a this side up label.
2026-10-25 v0.5 Hardware Changes
    - Added a location for a Wi-Fi module
    - Changed J2 to support +5V for the Wi-Fi module
    - Changed the artwork a bit and side up/down text
2026-10-26 Migrate hardware to KiCad 10

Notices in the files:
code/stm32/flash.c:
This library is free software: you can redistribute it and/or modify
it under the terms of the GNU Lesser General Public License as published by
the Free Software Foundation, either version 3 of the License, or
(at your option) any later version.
